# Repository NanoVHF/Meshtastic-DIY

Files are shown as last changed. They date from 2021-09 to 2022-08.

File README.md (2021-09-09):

# Meshtastic-DIY

Dear friends. If you have just learned what a Meshtastic-radio network is, if you are interested in the topic, if you already have a radio modem, and you would like to breathe life into it, then …
I have written a large series of 4 articles for the Russian-speaking community. This is more than the usual FAQ. This is a complete guide to action.
At the moment, the articles are written in Russian for a Russian-speaking audience. You can easily translate the article in your google chrome browser into your national language. Perhaps the Google translation will be slightly incorrect, with inaccuracies or errors.
Also, I am considering translating the article into real technical English.

PART 1 : https://habr.com/ru/post/568394/
The article is devoted to the general principles of the Meshtastic-network.

PART 2 : https://habr.com/ru/post/568526/
The article is devoted to branded radio modems with aliexpress stores.

PART 3 : https://habr.com/ru/post/568534/
The article is devoted to the radio amateur design and self-assembly of the radio modem (DIY).

PART 4 : https://habr.com/ru/post/569788/
A detailed step-by-step guide to flashing a radio modem and setting up a local radio network.

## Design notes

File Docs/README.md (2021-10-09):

# Documents

Documents, files and other text informations

* [Links](Links.md) - useful links
* [FAQ (ru)](FAQ_ru.md) - Frequently asced queries (in russian)
* LoRa modules V2 en.pdf - List of available LoRa modules
* LoRa modules V2.pdf - List of available LoRa modules (in russian) 
* Meshtastic DIY - Example of assembling a device on a 5x7 perforated board Translate.odt
* Meshtastic DIY - Пример сборки устройства на перфорированной плате 5x7 см.pdf
* Доклад на тему применения МШУ.pdf - paper about LNA using

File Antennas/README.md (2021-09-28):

# Meshtastic-DIY

Antenna drawings

[3El Yagee]("3El Yagee/") - Simple directional antenna

[Commercial](Commercial/) - Tested non-DIY antennas

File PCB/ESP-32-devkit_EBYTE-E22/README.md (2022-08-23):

# PCB

Based on [DIY v.1 shematics](https://github.com/NanoVHF/Meshtastic-DIY/tree/main/Schematics/E-Byte_E22) for using with `ESP32 WROOM-32 DevKit 38 pins` and `EBYTE E22-XXXM30S/E22-XXXM22S` modules.

Design by Denis Gorbunov (https://t.me/deaxx)

## Mesh-v1.01-2LCD-FreePins - Basic
- ESP32 WROOM-32 DevKit 38 pins,
- LORA: EBYTE E22-XXXM30S/E22-XXXM22S (selectable module). LoRa is connected via [an additional adapter board](#ebyte-e22-xxxmxxs-adapter-board),
- GPS,
- LCD (select different screens via jumpers: Vcc/GND or GND/Vcc),
- FR (free pins) - free ESP32 pins are placed along the edges of the board.

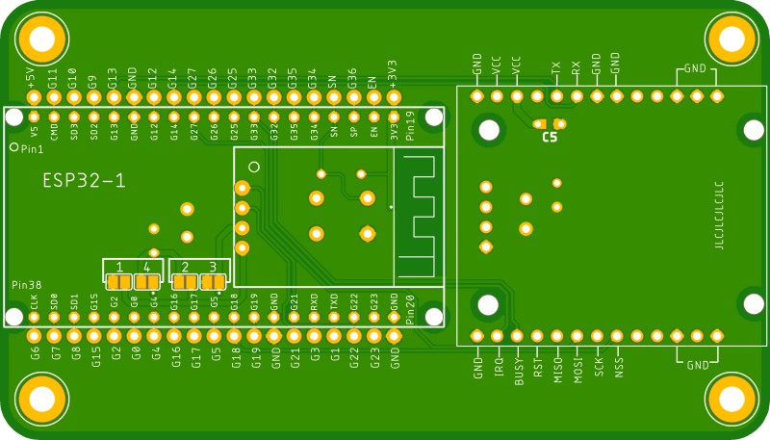
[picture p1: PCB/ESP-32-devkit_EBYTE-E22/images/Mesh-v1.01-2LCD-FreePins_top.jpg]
Mesh-v1.01-2LCD-FreePins_top

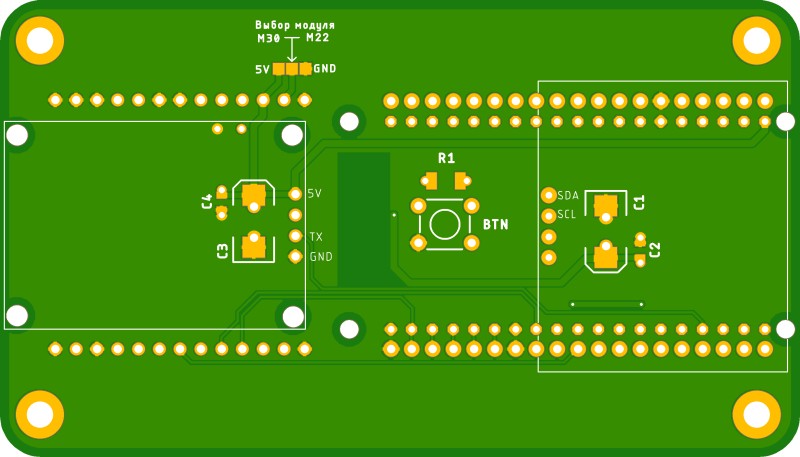
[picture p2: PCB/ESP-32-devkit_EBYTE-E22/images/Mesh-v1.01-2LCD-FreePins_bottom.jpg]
Mesh-v1.01-2LCD-FreePins_bottom


## Mesh-v1.02-2LCD - Narrow for placing inside a pipe
- ESP32 WROOM-32 DevKit 38 pins,
- LORA: EBYTE E22-XXXM30S/E22-XXXM22S (selectable module. LoRa module soldered directly to the board,
- GPS,
- LCD (select different screens via jumpers: Vcc/GND or GND/Vcc).

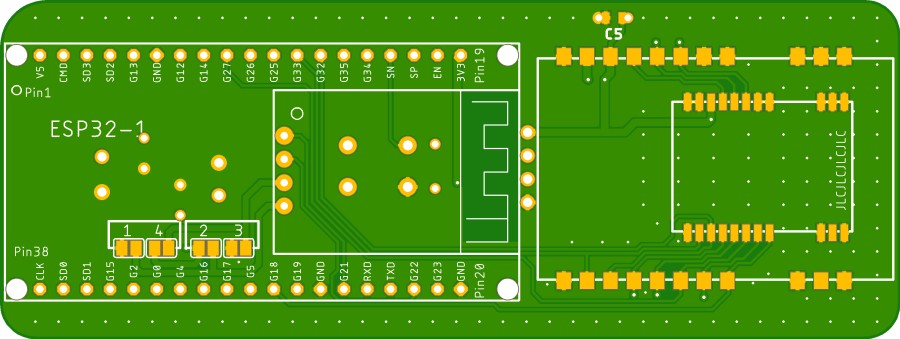
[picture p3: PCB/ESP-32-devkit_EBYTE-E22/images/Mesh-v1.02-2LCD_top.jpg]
Mesh-v1.02-2LCD_top

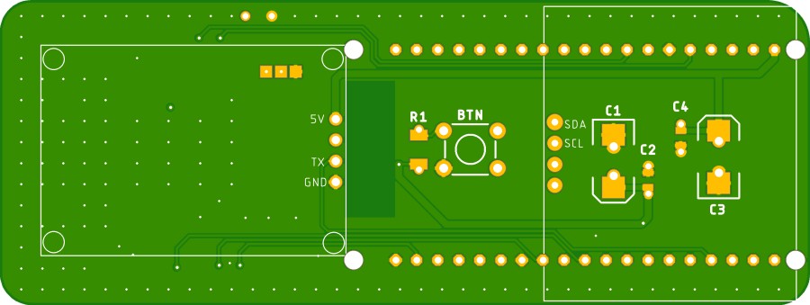
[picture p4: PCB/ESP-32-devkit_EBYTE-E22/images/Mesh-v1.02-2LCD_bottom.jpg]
Mesh-v1.02-2LCD_bottom


## Mesh-v1.02-2LCD-FreePins - Narrow for placing inside a pipe
- ESP32 WROOM-32 DevKit 38 pins,
- LORA: EBYTE E22-XXXM30S/E22-XXXM22S (selectable module. LoRa module soldered directly to the board,
- GPS,
- LCD (select different screens via jumpers: Vcc/GND or GND/Vcc),
- FR (free pins) - free ESP32 pins are placed along the edges of the board.

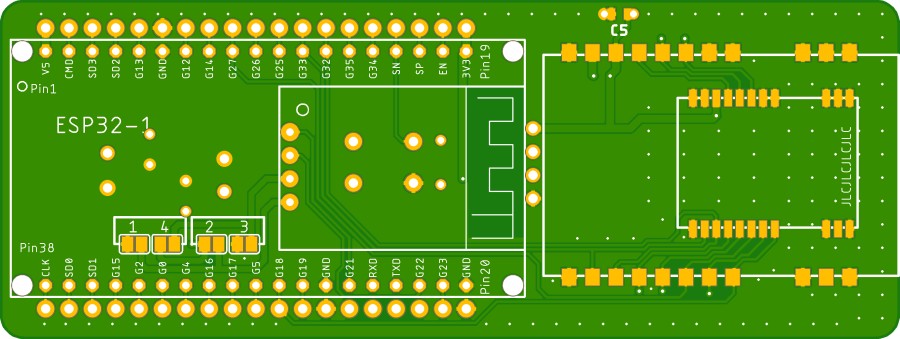
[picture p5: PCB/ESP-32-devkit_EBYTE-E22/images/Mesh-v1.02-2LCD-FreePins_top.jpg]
Mesh-v1.02-2LCD-FreePins_top

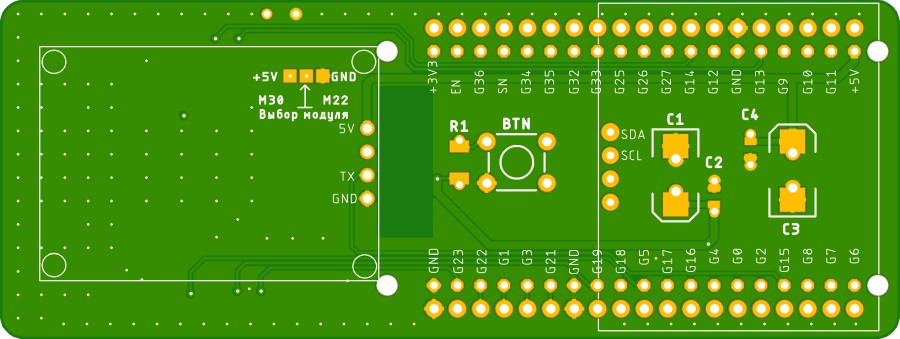
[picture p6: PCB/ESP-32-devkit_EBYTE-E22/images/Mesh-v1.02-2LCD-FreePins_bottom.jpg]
Mesh-v1.02-2LCD-FreePins_bottom


## Mesh-v1.03-2LCD-FreePins - Compact wearable
- ESP32 WROOM-32 DevKit 38 pins,
- LORA: EBYTE E22-XXXM30S/E22-XXXM22S (selectable module). LoRa is connected via [an additional adapter board](#ebyte-e22-xxxmxxs-adapter-board),
- GPS,
- LCD (select different screens via jumpers: Vcc/GND or GND/Vcc),
- FR (free pins) - free ESP32 pins are placed along the edges of the board.

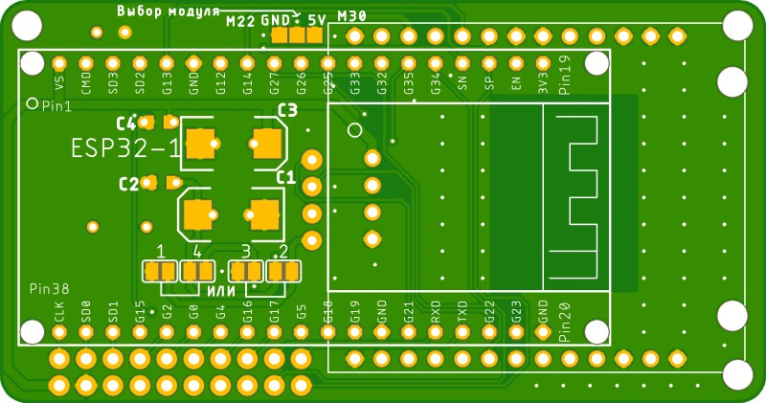
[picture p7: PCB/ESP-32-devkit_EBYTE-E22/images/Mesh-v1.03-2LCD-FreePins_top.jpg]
Mesh-v1.03-2LCD-FreePins_top

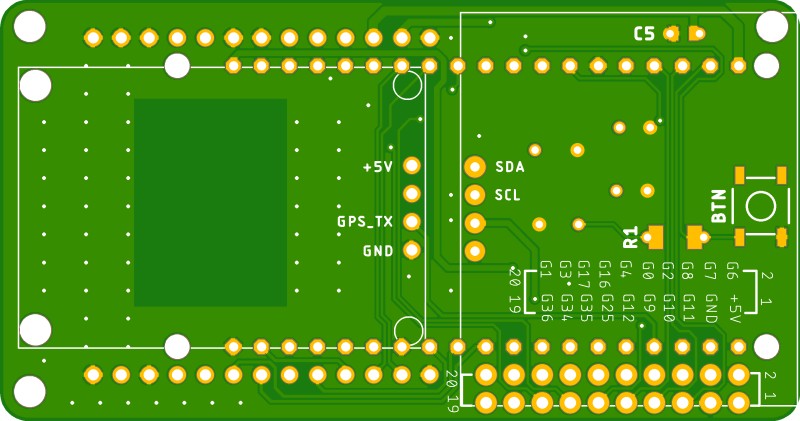
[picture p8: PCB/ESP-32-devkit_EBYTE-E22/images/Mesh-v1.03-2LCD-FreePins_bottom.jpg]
Mesh-v1.03-2LCD-FreePins_bottom


## Mesh-v1.04-TTGO-T8 - Compact wearable @ WROOWER T8 Lilygo
- ESP32 *WROOWER T8 Lilygo* 38 pins,
- LORA: EBYTE E22-XXXM30S/E22-XXXM22S (selectable module). LoRa is connected via [an additional adapter board](#ebyte-e22-xxxmxxs-adapter-board),
- GPS,
- LCD (select different screens via jumpers: Vcc/GND or GND/Vcc),
- FR (free pins) - free ESP32 pins are placed along the edges of the board.

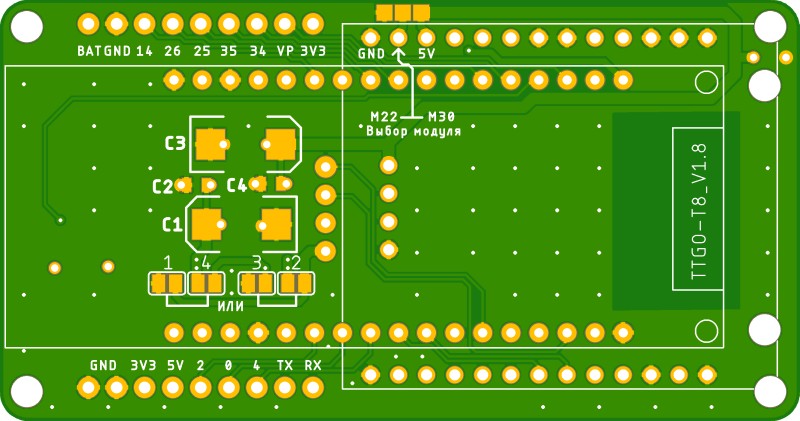
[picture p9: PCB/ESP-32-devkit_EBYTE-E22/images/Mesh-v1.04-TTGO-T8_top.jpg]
Mesh-v1.04-TTGO-T8_top

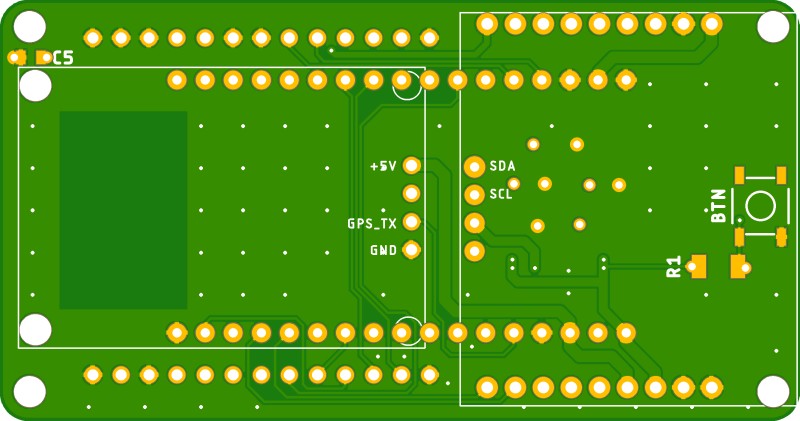
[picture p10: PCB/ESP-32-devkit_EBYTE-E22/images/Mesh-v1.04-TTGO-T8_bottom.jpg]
Mesh-v1.04-TTGO-T8_bottom


## Meshtastic-DIY_v1.05 - Square one
- ESP32 WROOM-32 DevKit 38 pins,
- LORA: EBYTE E22-XXXM30S/E22-XXXM22S (selectable module),
- GPS,
- LCD (select different screens via jumpers: Vcc/GND or GND/Vcc),
- Optional active buzzer.

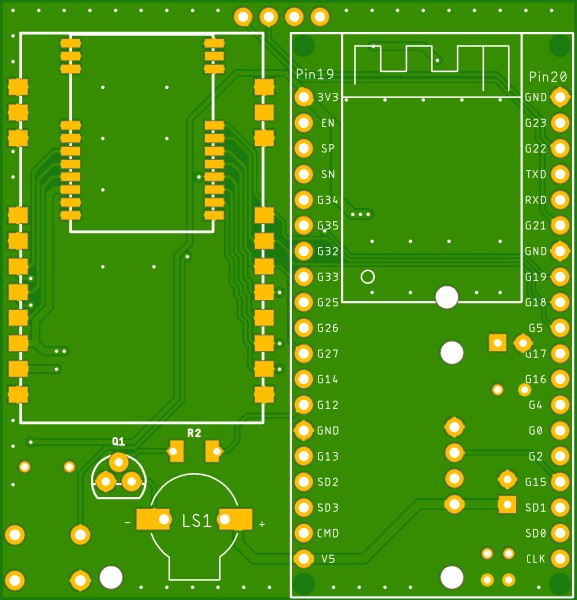
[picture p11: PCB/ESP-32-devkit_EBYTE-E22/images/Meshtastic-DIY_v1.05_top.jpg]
Meshtastic-DIY_v1.05_top

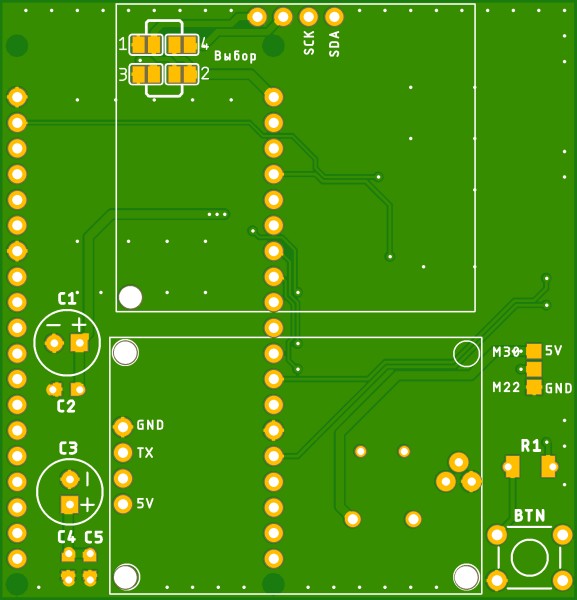
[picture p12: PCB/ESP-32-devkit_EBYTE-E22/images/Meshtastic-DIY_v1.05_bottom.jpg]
Meshtastic-DIY_v1.05_bottom


## Meshtastic-DIY_v1.06 - TTGO T-Energy T18 V3.0 HAT
- *Lilygo TTGO T-Energy T18 V3.0*,
- LORA: EBYTE E22-XXXM30S/E22-XXXM22S (selectable module),
- LCD (select different screens via jumpers: Vcc/GND or GND/Vcc).

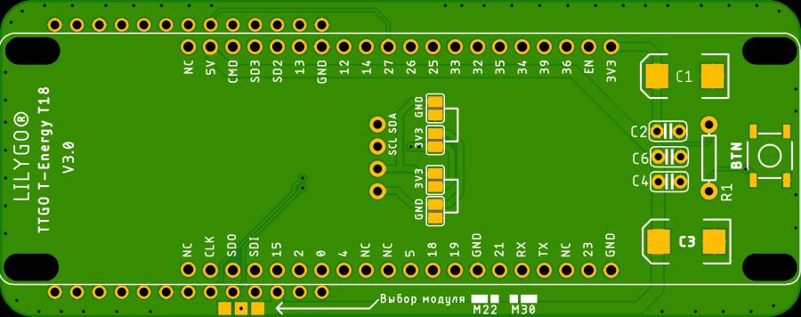
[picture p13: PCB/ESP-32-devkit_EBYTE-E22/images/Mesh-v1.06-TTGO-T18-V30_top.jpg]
Mesh-v1.06-TTGO-T18-V30_top

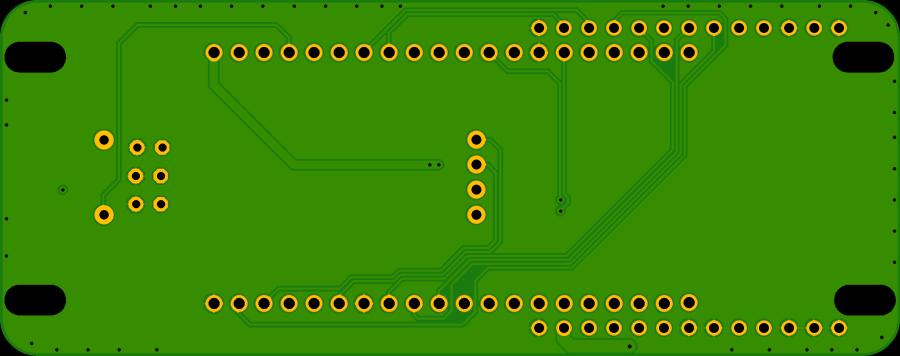
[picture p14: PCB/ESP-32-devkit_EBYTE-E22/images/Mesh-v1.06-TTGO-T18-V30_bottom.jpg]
Mesh-v1.06-TTGO-T18-V30_bottom


## EBYTE E22-xxxMxxS adapter board
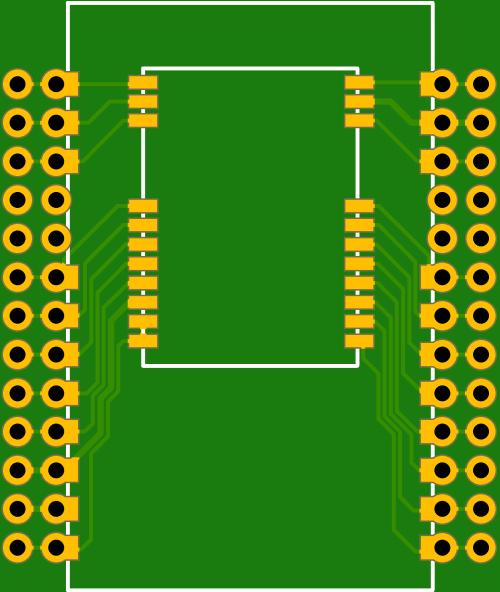
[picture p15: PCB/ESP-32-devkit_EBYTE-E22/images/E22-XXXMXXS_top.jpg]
E22-XXXMXXS_top

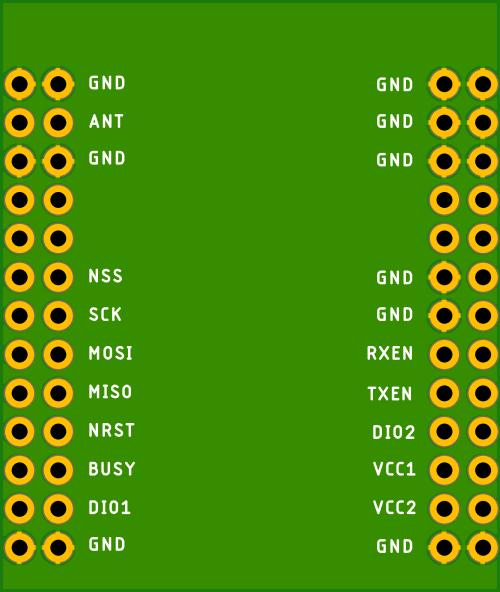
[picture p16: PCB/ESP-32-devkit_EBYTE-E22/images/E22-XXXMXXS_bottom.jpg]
E22-XXXMXXS_bottom


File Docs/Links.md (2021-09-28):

# Useful links

## Common links

* [Meshtastic.org](https://meshtastic.org/) - main site of project
* [Meshtastic.ru](https://meshtastic.ru/) - site of russian meshtastic team
* [Meshtastic map](https://canvis.app/meshtastic-map) - map of meshtastic nodes
* [Meshtastic forum](https://meshtastic.discourse.group) - meshtastic forum at discourse.group

## Hardware

* [Aliexpress aluminium case](https://aliexpress.ru/item/32226417158.html) - aluminium case for PCB 45x45x18.5 mm external
* [Aliexpress IPEX-SMA pigtail](https://aliexpress.ru/item/4001038251087.html) - IPEX/IPX/U.fl jack to SMA socket pigtail with seal
* [Aliexpress IPEX-SMA pigtail](https://aliexpress.ru/item/4000979336586.html) - IPEX/IPX/U.fl jack to SMA jack pigtail
* [Aliexpress IPEX to SMA converter](https://a.aliexpress.com/_AlJSeS) - unchecked
* [Aliexpress IPEX to SMA converter 2](https://a.aliexpress.com/_AE24qa) - unchecked
* [Aliexpress base antenna 868 MHz](https://a.aliexpress.com/_AtphUu) - base station antenna with N type jack
* [Aliexpress antenna 868 MHz](https://aliexpress.ru/item/32972870968.html) - in-hole antenna with U.fl type jack
* [Antenna on magnetic base 868 MHz](https://www.triada-ant.ru/catalogue/antenny/2/11/133/) - unchecked

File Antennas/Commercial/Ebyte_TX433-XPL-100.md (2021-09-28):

# Ebyte TX433-XPL-100 

Ebyte TX433-XPL-100 Antenna 433MHz High Gain SMA jack Magnetic Base Omnidirectional 1m feeder 

Purchase link (to 2m feeder version) https://a.aliexpress.com/_AdqBiV

Inexpencive lambda/4 whip antenna.

Test setup: NanoVNA V2 china clone, NanoVNA_QT_GUI profram, canned peaches can. Sweep from 390 to 470 MHz, 200 poins.

[Impedances](TX433-XPL-100.csv)

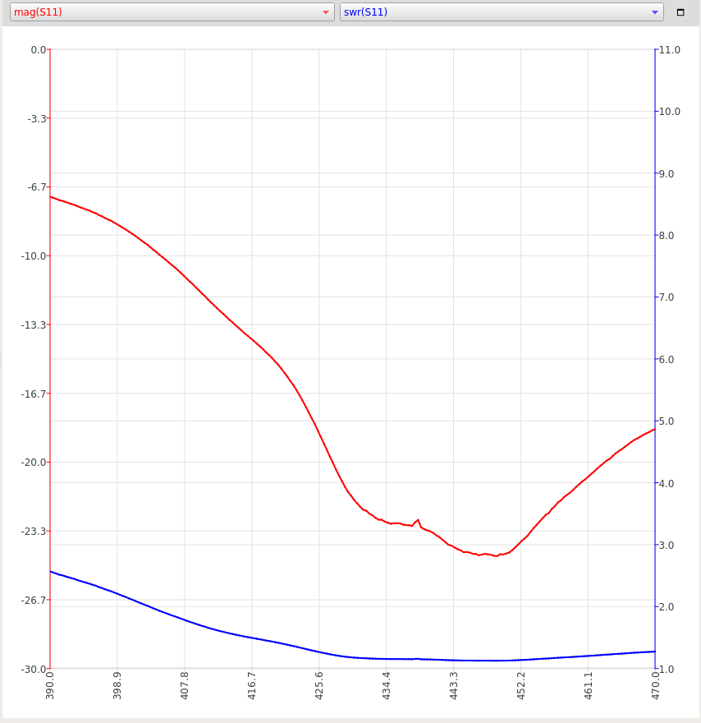
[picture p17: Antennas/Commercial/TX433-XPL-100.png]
SWR graph


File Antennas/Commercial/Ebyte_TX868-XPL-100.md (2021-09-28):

# Ebyte TX868-XPL-100 

Ebyte TX868-XPL-100 Antenna 868MHz 3.5dBi High Gain Omnidirectional SMA Interface Magnetic Base 1m Feeder 

Purchase link: https://a.aliexpress.com/_987405

Inexpencive collinear antenna.

Test setup: NanoVNA V2 china clone, NanoVNA_QT_GUI profram, canned peaches can. Sweep from 790 to 950 MHz, 200 poins.

[S11 parameters](TX868-XPL-100.s1p), [impedances](TX868-XPL-100.csv)

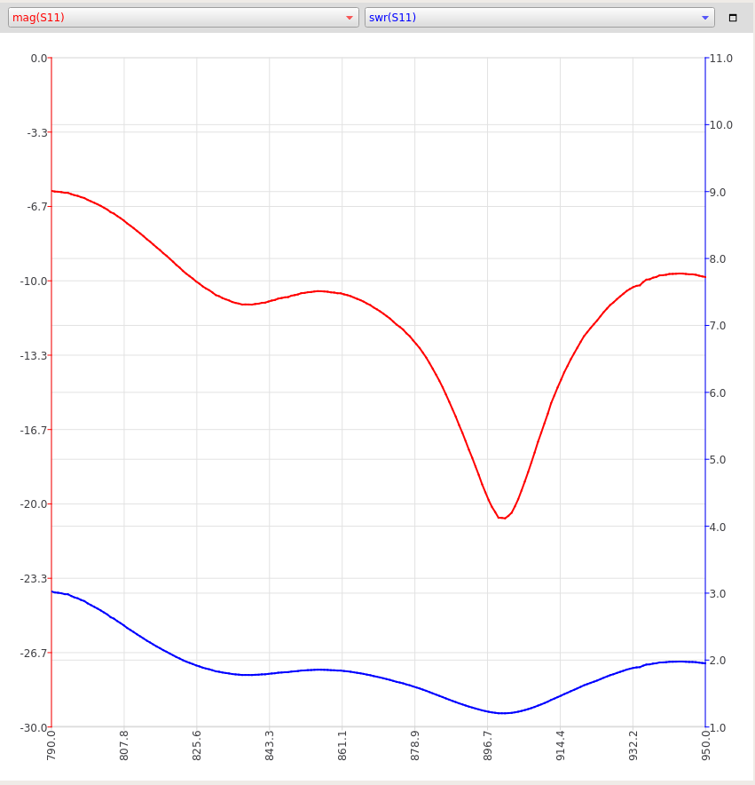
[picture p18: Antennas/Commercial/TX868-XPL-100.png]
SWR graph


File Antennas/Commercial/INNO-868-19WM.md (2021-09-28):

# INNO-868-19WM

White 868MHz LORA Antenna SMA Male Connector 868 MHz 21cm RP-SMA/u.FL Pigtail Cable

Purchase link: https://a.aliexpress.com/_AY2JaH

Test setup: NanoVNA V2 china clone, NanoVNA_QT_GUI profram, canned peaches can. Sweep from 790 to 950 MHz, 200 poins.

[S11 parameters 1](INNO-868-19WM.s1p), [2](INNO-868-19WM-2.s1p), [mpedance](INNO-868-19WM.csv)

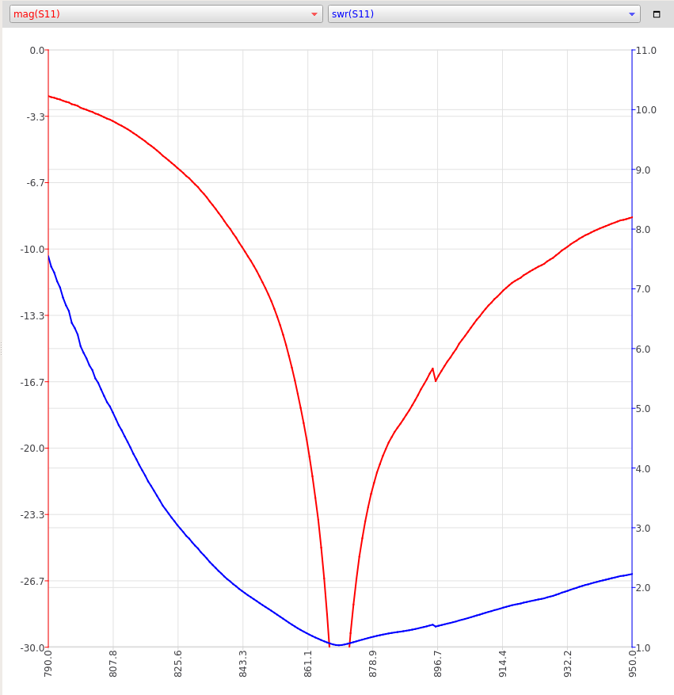
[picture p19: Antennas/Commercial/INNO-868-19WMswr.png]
SWR graph


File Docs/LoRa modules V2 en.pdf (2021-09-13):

### E-byte modules

Module | Chip | Freq (MHz) | PWR (dBm) | Uvdd (V) | Peculiarities | Price $
E22-900M22S | SX1262 | 868 | 22 | 3.3 | Simple module. No LNA. No PA. Has TCXO. | 9
E22-900M30S | SX1262 | 868 | 30 | 5 | Powerful module. Has LNA. Has PA. Has TCXO. | 11
E22-400M22S | SX1268 | 433 | 22 | 3.3 | Simple module. No LNA. No PA. Has TCXO. | 6
E22-400M30S | SX1268 | 433 | 30 | 5 | Powerful module. Has LNA. Has PA. Has TCXO. | 10
E19-868M30S | SX1276 | 868 | 30 | 5 | Powerful module. Has LNA. Has PA. No TCXO. | 10…12
E19-868M20S | SX1276 | 868 | 20 | 3.3 | Simple module. No LNA. No PA. No TCXO. | 5…6
E19-900M20S2 | SX1276 | 868 | 20 | 3.3 | Simple module. No LNA. No PA. No TCXO. | 4…5
E19-433M30S | SX1278 | 433 | 30 | 5 | Powerful module. Has LNA. Has PA. No TCXO. | 6…7
E19-433M20SC | SX1278 | 433 | 20 | 3.3 | Simple module. No LNA. No PA. No TCXO. | 4…5
E19-433M20S2 | SX1278 | 433 | 20 | 3.3 | Simple module. No LNA. No PA. No TCXO. | 4…5
E220-900M22S | LLCC68 | 868 | 22 | 3.3 | Simple module. No LNA. No PA. ? TCXO. | 3…5
E220-900M30S | LLCC68 | 868 | 30 | 5 | Powerful module.. Has LNA. Has PA. ? TCXO. | ?
E220-400M22S | LLCC68 | 433 | 22 | 3.3 | Simple module No LNA. No PA. ? TCXO. | 3…4
E220-400M30S | LLCC68 | 433 | 30 | 5 | Powerful module Has LNA. Has PA. ? TCXO. | ?

Prices are indicative for EBYTE IOT Factory Store or CDSENET IOT Module Store

### G-NiceRF modules

Module | Chip | Freq (MHz) | PWR (dBm) | Uvdd (V) | Peculiarities | Price $
LoRa1262F30 | SX1262 | 868 | 30 | 5…6 | Powerful module. No LNA. Has PA. Has TCXO. | 12…14
LoRa1262F30 | SX1262 | 315 | 30 | 5…6 | Powerful module. No LNA. Has PA. Has TCXO. | 12…14
LoRa1268F30 | SX1268 | 433 | 30 | 5…6 | Powerful module. No LNA. Has PA. Has TCXO. | 14
LoRa1262-868 | SX1262 | 868 | 22 | 3.3 | Simple module. No LNA. No PA. Has TCXO. | 9
LoRa1268-433 | SX1268 | 433 | 22 | 3.3 | Simple module. No LNA. No PA. Has TCXO. | 10…14
LoRa1276-C1-868 | SX1276 | 868 | 20 | 3.3 | Simple module. No LNA. No PA. No TCXO. | 5…7
LoRa1278-C1-433 | SX1278 | 433 | 20 | 3.3 | Simple module. No LNA. No PA. NO TCXO. | 5…7
LoRa-CC68-868 | LLCC68 | 868 | 22 | 3.3 | Simple module. No LNA. No PA. ? TCXO. | 4
LoRa-CC68-433 | LLCC68 | 433 | 22 | 3.3 | Simple module. No LNA. No PA. ? TCXO. | 4
LoRa1276F30 | SX1276 | 868 | 27 | 5…6 | Powerful module. No LNA. Has PA. No TCXO. | 13
LoRa1278F30 | SX1278 | 433 | 30 | 5…6 | Powerful module. No LNA. Has PA. No TCXO. | 13
LoRa1276-868 | SX1276 | 868 | 20 | 3.3 | Simple module. No LNA. No PA. No TCXO. | 7
LoRa1278-433 | SX1278 | 433 | 20 | 3.3 | Simple module. No LNA. No PA. No TCXO. | 7

Prices are indicative for G-NiceRF Official Store or NiceRF Wireless Technology CO., LTD. Modules are usually sold in 2 or 4 pieces.

Green color:- modules are officially supported by firmware and / or tested.

Yellow color: -modules are not officially supported by firmware, but have already been tested.

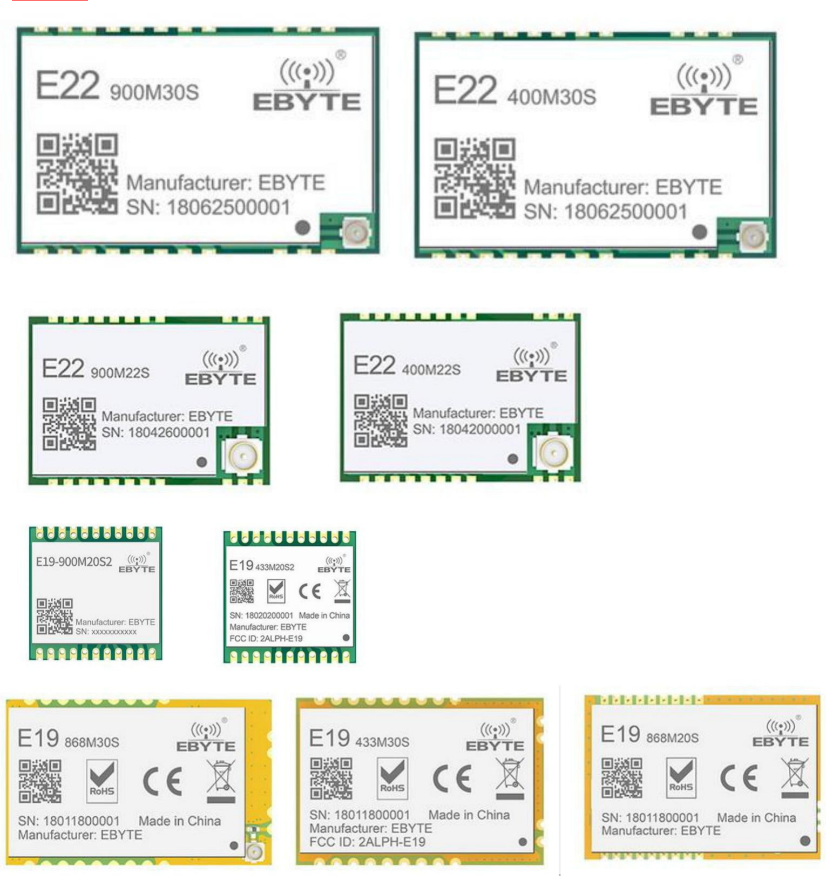
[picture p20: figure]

Color red: -modules are not officially supported by firmware, not tested but work is in progress.

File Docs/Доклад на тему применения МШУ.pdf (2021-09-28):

Расширенный доклад на тему применения МШУ.

Когда вы увидели некое китайское поделие на досках Али или Ебай под видом МШУ за относительно небольшие деньги, то не нужно бросаться и сразу заказывать его. Это же В ОСОБЕННОСТИ относится к телевизионным усилителям.

Объясняю почему. Сегодняшний уровень прогресса уже давно дошел да того, что одночиповые трансиверы типа SI4432, SX1276/SX1262, BK4815
трансиверов | Zastone | или | QYTа | или | подобные | изделия | (включая
супергетеродины типа Wouxun и Аргут) обеспечивают чуйку в пределах 0,2мкВ или, даже, лучше. Ставить МШУ на подобные аппараты смысла нет никакого!
- Во-первых: улучшений вы скорее всего не увидите;
- Во-вторых: испортите и без того не сильно высокие динамические характеристики «однояицовых» аппаратов. Исключение – сильно специфичные условия, типа 50м до крыши, но там отдельная тема разговора, смысл которой – сделать правильную коммутацию и питание.

Начните с того, что делайте лучше нормальные антенны - и будет вам аж счастье-СЧАСТЬЕ! Не Харченки всякие линейные и не рулеточные диполи, а хотя бы 6...8 эл Яги, а ещё лучше - монобендовые крестики. Да, это довольно трудоёмко, зато – есть эффект. И совсем круто будет - когда вы начнёте крутить мышам хвосты в спирали. Начинать нужно смело от 3х витков. Антенна получается достаточно простой и не сильно габаритной. Тогда ГШ сильно опечалится и сбежит нах, ибо никто не будет на неё реагировать.

Теперь по поводу конкретно МШУ, продаваемых на АЛИ

Во-первых, никакой гарантии, что вам их продадут нормальные и фирменные нет. У меня большой опыт закупок подобной СВЧ лабуды, не только для дома, а и для производства. Даже на фирмах бывает залипуху подсовывают; во-вторых, когда китайцы пишут полосу 0Гц - 100тыс. гигаерц и усиление 20...1000дБ – это 250% обман! Почему так? В даташитах на некоторые МС, действительно, пишут полосу работы от 50МГц до 6ГГц усиление 12...20дБ. Но, это в строго конкретном участке частот, куда микросхема идеально отстроена, а это значит, что натуральные 12...20дБ усиления будут примерно в полосе 50...100МГц. Т.е. эти МС надо обязательно согласовывать туда, куда их планируется использовать. Во всей остальной полосе будет повышенный уровень шума, гораздо ниже усиление и вообще, несогласованная работа микросхем МШУ чревата "художественным свистом" с последующим выгоранием.

Основные ТТХ МШУ

Основной характеристикой МШУ является уровень собственных шумов. Относительно ЧЕГО? По отношению к вносимым шумам последующего за МШУ каскада, в реальности – к космическим шумам эфира и шумовой обстановки вокруг антенны. Применять МШУ есть смысл, когда антенна сама по себе имеет малый коэф. усиления и/или когда надо компенсировать потери в длинном кабеле.

- Главный параметр МШУ - "Коэффициент шума (Кш)"

Хорошая цифра Кш - это 0,5...1. Меньше 0.2 Кш получить технически очень сложно и страшно дорого. Когда китайцы пишут про 0.1дБ на спутниковой головке – это, тоже чистый обман! Из доступных МШУ в России на сегодняшний день – это МС серий SPF, BGA и некоторые MGA с Кш=0,5...1,5дб. Всё что имеет Кш лучше чем 0.5 – достать обычному
смертному | практически | невозможно, | (топовые | изделия | оборонного
назначения находятся под санкциями и в Россию поставки официально запрещены) чего бы там китайцы не писали про свои поделки! Обычно Кш<1 в китайских поделиях тоже нет. (Исключения есть, но это надо очень сильно заморочиться с поисками). Залипуху с неизвестной перемаркировкой и подделками под оригинальные SPF вообще не рассматриваем. Что там китайцы запаяли – неизвестно.

МШУ с Кш>3 – это явно плохие устройства, т.к. улучшение сигнала всего на 1-3дБ с практической точки зрения не имеют смысла. Такой МШУ назвать малошумящим язык даже не поворачивается назвать.

Для реализации всех преимуществ малошумящих микросхем требуется очень хорошая экранировка самого тракта МШУ, очень чистое питание и главное -подходящий не фонящий QTH. В городе реализовать параметры такого МШУ практически, в 99% случаев невозможно, т.к. сам радиоэфир имеет большой уровень помех.

Коэффициент шума большинства раций составляет 5-10дБ. Если мы применяем МШУ с коэф. шума =1, то улучшаем приём на разницу между этими коэффициентами. Т.е. в данном случае на те же 5-10дБ. По шкале Sметра – это 1-3 балла. В реальном же эфире – это возможность услышать сигнал, который в обычном состоянии находится примерно под шумами рации, в том случае, если антенна позволяет принять сигнал на более качественном приёмнике.

Как говорилось выше – большинство современных приёмников имеют вполне неплохой приёмный тракт, а сигналы со спутников относительно сильные. (Относительно — это значит, что транспондеры видно и слышно на обычный диполь, и специально применения МШУ не требуется)

- Параметр "Коэффициент усиления"

Ку имеет смысл, но он в большинстве случаев вторичен.

Высокий | уровень | усиления | на | практике | позволяет
"прошить"/скомпенсировать потери на длинном кабеле. В особенности, это касается частот выше 500…700МГц, где потери на длине кабеля от 10м и длиннее, довольно существенны.

Скажем, если у вас антенна на крыше дома, а вы на 1-5 этажах от 9-этажки, то МШУ с малым уровнем шума и высоким Ку позволит существенно улучшить качество приёма имеющейся станции.

Высокий уровень усиления МШУ на балконной антенне кроме как увеличения уровня принимаемого шума в большинстве случаев мало что даст. Тут, как раз, существенно сказывается уровень шумов в вашем QTH: шумы от всяких импульсных БК, компьютеров и проводов.

- Параметры ОТЛИЧНОГО МШУ: Кш=0.3...0.5дБ; Ку=20...25дБ (спец. транзисторы; SPF5122 и др.)
- Параметры ХОРОШЕГО МШУ: Кш=0.5...1дБ; Ку=15...20дБ (ATF54143; SPF5043 и др.)
- Параметры ПРИЕМЛЕМОГО МШУ: Кш1.2...1.8дБ; Ку=12...15дБ (транзисторы типа BF998 и похожие)

ВСЁ ЧТО ХУЖЕ ЭТИХ ПАРАМЕТРОВ НЕ ИМЕЕТ СМЫСЛА ПОКУПАТЬ ОТ СЛОВА СОВСЕМ!!!

Абсолютное большинство ТВ усилителей относятся к классу "плохих", т.е. сильно шумящих усилителей!... за, очень редким исключением.

Всем спасибо за внимание, доклад окончил.

Александр: @ Nano_VHF

Релиз: декабрь 2017г.

UPD: 28.09.2021

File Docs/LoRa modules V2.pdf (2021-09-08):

### E-byte modules

Module | Chip | Freq (MHz) | PWR (dBm) | Uvdd (V) | Peculiarities | Price $
E22-900M22S | SX1262 | 868 | 22 | 3.3 | Простой модуль. Нет LNA. Нет PA. Есть TCXO. | 9
E22-900M30S | SX1262 | 868 | 30 | 5 | Мощный модуль. Есть LNA. Есть PA. Есть TCXO. | 11
E22-400M22S | SX1268 | 433 | 22 | 3.3 | Простой модуль. Нет LNA. Нет PA. Есть TCXO. | 6
E22-400M30S | SX1268 | 433 | 30 | 5 | Мощный модуль. Есть LNA. Есть PA. Есть TCXO. | 10
E19-868M30S | SX1276 | 868 | 30 | 5 | Мощный модуль. Есть LNA. Есть PA. Нет TCXO. | 10…12
E19-868M20S | SX1276 | 868 | 20 | 3.3 | Простой модуль. Нет LNA. Нет PA. Нет TCXO. | 5…6
E19-900M20S2 | SX1276 | 868 | 20 | 3.3 | Простой модуль. Нет LNA. Нет PA. Нет TCXO. | 4…5
E19-433M30S | SX1278 | 433 | 30 | 5 | Мощный модуль. Есть LNA. Есть PA. Нет TCXO. | 6…7
E19-433M20SC | SX1278 | 433 | 20 | 3.3 | Простой модуль. Нет LNA. Нет PA. Нет TCXO. | 4…5
E19-433M20S2 | SX1278 | 433 | 20 | 3.3 | Простой модуль. Нет LNA. Нет PA. Нет TCXO. | 4…5
E220-900M22S | LLCC68 | 868 | 22 | 3.3 | Простой модуль. Нет LNA. Нет PA. ? TCXO. | 3…5
E220-900M30S | LLCC68 | 868 | 30 | 5 | Мощный модуль. Есть LNA. Есть PA. ? TCXO. | ?
E220-400M22S | LLCC68 | 433 | 22 | 3.3 | Простой модуль. Нет LNA. Нет PA. ? TCXO. | 3…4
E220-400M30S | LLCC68 | 433 | 30 | 5 | Мощный модуль. Есть LNA. Есть PA. ? TCXO. | ?

Цены указаны ориентировочно для магазинов EBYTE IOT Factory Store или CDSENET IOT Module Store

### G-NiceRF modules

Module | Chip | Freq (MHz) | PWR (dBm) | Uvdd (V) | Peculiarities | Price $
LoRa1262F30 | SX1262 | 868 | 30 | 5…6 | Мощный модуль. Нет LNA. Есть PA. Есть TCXO. | 12…14
LoRa1262F30 | SX1262 | 315 | 30 | 5…6 | Мощный модуль. Нет LNA. Есть PA. Есть TCXO. | 12…14
LoRa1268F30 | SX1268 | 433 | 30 | 5…6 | Мощный модуль. Нет LNA. Есть PA. Есть TCXO. | 14
LoRa1262-868 | SX1262 | 868 | 22 | 3.3 | Простой модуль. Нет LNA. Нет PA. Есть TCXO. | 9
LoRa1268-433 | SX1268 | 433 | 22 | 3.3 | Простой модуль. Нет LNA. Нет PA. Есть TCXO. | 10…14
LoRa1276-C1-868 | SX1276 | 868 | 20 | 3.3 | Простой модуль. Нет LNA. Нет PA. Нет TCXO. | 5…7
LoRa1278-C1-433 | SX1278 | 433 | 20 | 3.3 | Простой модуль. Нет LNA. Нет PA. Нет TCXO. | 5…7
LoRa-CC68-868 | LLCC68 | 868 | 22 | 3.3 | Простой модуль. Нет LNA. Нет PA. ? TCXO. | 4
LoRa-CC68-433 | LLCC68 | 433 | 22 | 3.3 | Простой модуль. Нет LNA. Нет PA. ? TCXO. | 4
LoRa1276F30 | SX1276 | 868 | 27 | 5…6 | Мощный модуль. Нет LNA. Есть PA. Нет TCXO. | 13
LoRa1278F30 | SX1278 | 433 | 30 | 5…6 | Мощный модуль. Нет LNA. Есть PA. Нет TCXO. | 13
LoRa1276-868 | SX1276 | 868 | 20 | 3.3 | Простой модуль. Нет LNA. Нет PA. Нет TCXO. | 7
LoRa1278-433 | SX1278 | 433 | 20 | 3.3 | Простой модуль. Нет LNA. Нет PA. Нет TCXO. | 7

Цены указаны ориентировочно для магазинов G-NiceRF Official Store или NiceRF Wireless Technology CO.,LTD.

Модули обычно продаются по 2шт или 4шт.

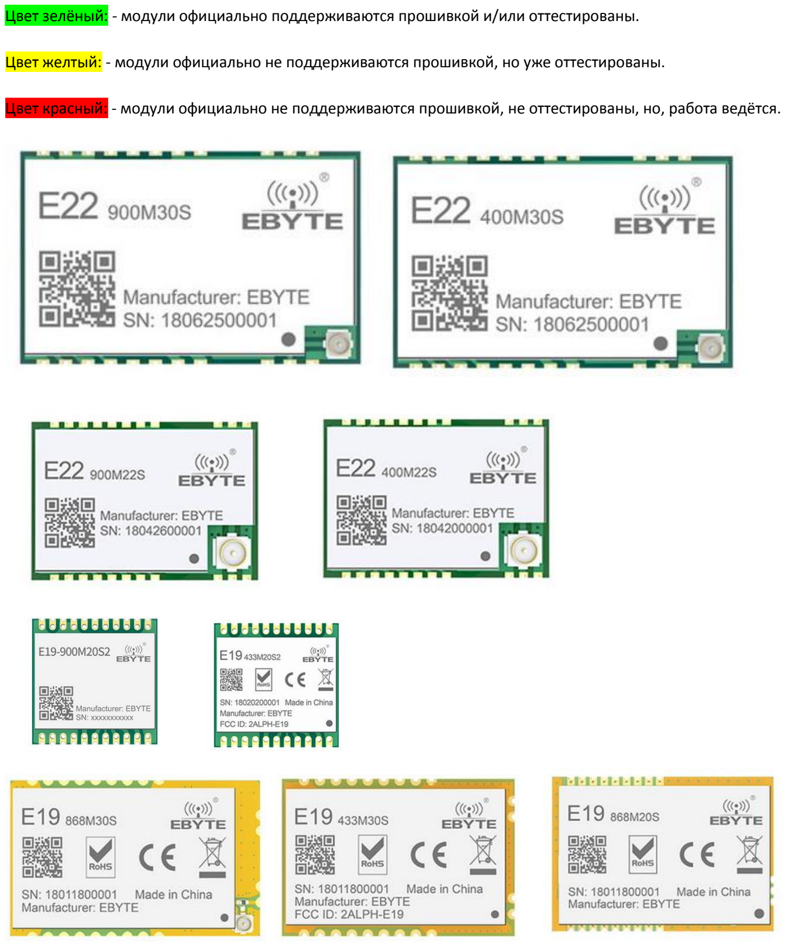
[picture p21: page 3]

Цвет зелёный: - модули официально поддерживаются прошивкой и/или оттестированы.

Цвет желтый: - модули официально не поддерживаются прошивкой, но уже оттестированы.

Цвет красный: - модули официально не поддерживаются прошивкой, не оттестированы, но, работа ведётся.

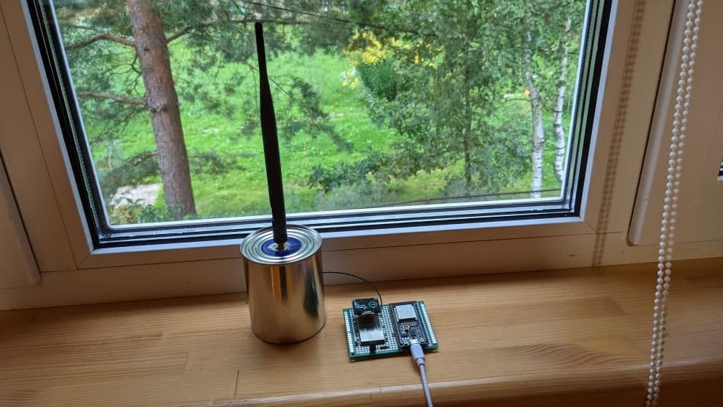
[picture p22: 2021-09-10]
Photos/Design_1.jpg

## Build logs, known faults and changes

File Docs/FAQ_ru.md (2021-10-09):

# ЧаВо (FAQ на русском)

Часто задаваемые вопросы и ответы, собранные с разных сайтов, форумов и чатов

## Общие вопросы

### Что такое Meshtastic ?

Meshtastic - самоорганизующаяся радиосеть передачи текстовых сообщений на основе технологии LoRa. 

### А подробнее?

Сеть Meshtastic состоит из смартфонов (пока только под андроидом) и вспомогательных устройств, которые связаны со смартфоном по интерфейсу Bluetooth, а между собой - по радио с использованием технологии LoRa. На смартфоны ставится клиент, с точки зрения пользователя - мессенджер, который обменивается сообщениями с вышеупомянутым устройством. Дальше они передают сообщения по радиоканалу на так называемых безлицензионных частотах (в России диапазоны 433 и 868 МГц). Каждое устройство может быть ещё и ретранслятором, автоматически обнаруживать новые устройства в эфире и строить таблицу маршрутизации сообщений.

Просто почитать сообщения можно и без смартфона, если устройство оборудовано экраном и кнопками навигации. На самых дешевых вариантах их (сюрприз, сюрприз) нет.

В любом варианте система Meshtastic позволяет без какой-либо дополнительной инфраструктуры, то есть там и тогда, где не работает сотовая связь, интернет и другие блага цивилизации, поддерживать связь друг с другом.

### Законно ли это ?

Использование LoRa устройств законно и не требует лицензии при условии соблюдения региональных ограничений на мощность и диапазон частот передатчика. В Российской Федерации это 25 мВт и диапазоны EU433 и RU864-870, описанные в документе [RP2-1.0.2 LoRaWAN® Regional Parameters](https://lora-alliance.org/resource_hub/rp2-102-lorawan-regional-parameters/) Исключение - территории аэродромов и аэропортов.

На русском языке это кратко описано [в статье на сайте русского альянса производителей интернета вещей](https://iotas.ru/media/news_aiv/161/).

Основание - [решение ГКРЧ при Мининформсвязи России №07-20-03-001 от 07.05.2007 "О выделении полос радиочастот устройствам малого радиуса действия" (действует до мая 2027 года)](https://digital.gov.ru/ru/documents/4039/), приложение №11. [Статья с кратким изложением](https://itechinfo.ru/content/%D1%81%D1%82%D1%80%D0%BE%D0%B8%D1%82%D0%B5%D0%BB%D1%8C%D1%81%D1%82%D0%B2%D0%BE-%D1%81%D0%B5%D1%82%D0%B5%D0%B9-lora-%D0%B2-%D1%80%D1%84)

### Где почитать подробнее?

Документация на русском языке пока в процессе перевода. Если же вы читаете технический английский, вам дорога на сайт [Meshtastic.org](https://meshtastic.org/)

### Здесь могут быть ваши вопросы 

## Вопросы начинающих

### С чего начать?

Минимальный план действий:

* Приобрести оборудование
* Прошить в него нужную фирмварь
* Подключить к нему смартфон
* Наслаждаться общением

Прошивка оборудования описана на том же сайте в разделах [Flashing ESP32](https://meshtastic.org/docs/getting-started/flashing-esp32) и [Flashing nRF52](https://meshtastic.org/docs/getting-started/flashing-nrf52) для устройств на микроконтроллерах ESP32 и nRF52 соответственно

Подключение смартфона (пока только с андроидом) описано [в соответствующем разделе сайта мештастика](https://meshtastic.org/docs/software/android/android-installation)

### Здесь могут быть ваши вопросы 

## Технические вопросы

### Можно ли построить на одном радиомодеме двухдиапазонное устройство?

Нет. Хотя некоторые микросхемы, например, семейства SX126x по спецификации поддерживают широкий диапазон частот, антенны и входящие в радиомодули усилители и схемы согласования узкополосны и работают лишь в том диапазоне частот, на который рассчитан модуль.

### Здесь могут быть ваши вопросы

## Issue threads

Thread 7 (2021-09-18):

Custom PCB

puzzled-pancake, 2021-09-18:
I designed a custom PCB based on the schematic.
I am not a professional in designing or making PCBs please tell me if I made a mistake or if you want to add anything else to the PCB.

Cost for 5 PCBs from China is $6.20 usd + Shipping

This is based on 38 Pin ESP32 board.

https://github.com/puzzled-pancake/Meshtastic-DIY/tree/main/Schematics/Meshtastic%20PCB%20untested

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

puzzled-pancake, 2021-09-18:
**Russian translated using google translate**
Я разработал собственную печатную плату на основе схемы.
Я не профессионал в проектировании или изготовлении печатных плат, пожалуйста, скажите мне, если я допустил ошибку, или если вы хотите добавить что-нибудь еще к печатной плате.

Стоимость 5 печатных плат из Китая - 6.20 долларов США + доставка

Это основано на 38-контактной плате ESP32.

https://github.com/puzzled-pancake/Meshtastic-DIY/tree/main/Schematics/PCB%20Example%20test

osmanovv, 2021-09-18:
Could you please also sketch it for the 30-pins version of ESP32-WROOM-32 DevKit?

osmanovv, 2021-09-18:
And perhaps variants with a horizontal layout

puzzled-pancake, 2021-09-19:
> Could you please also sketch it for the 30-pins version of ESP32-WROOM-32 DevKit?

Done a 30 pin vertical I will work on a horizontal layout for the 30pin and 38pin

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

puzzled-pancake, 2021-09-19:
Is this horizontal layout okay?

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

zonder16, 2021-11-15:
Could you please also sketch it for the version of LILYGO®TTGO T8 V1.8 ESP32 - WROVER 8MB PSRAM TF? [Liligo ttgo t8](https://a.aliexpress.com/_9wNify)

NanoVHF, 2022-07-08:
Tested versions of boards: https://github.com/NanoVHF/Meshtastic-DIY/tree/main/PCB/ESP-32-devkit_EBYTE-E22

Closed 2022-07-08.

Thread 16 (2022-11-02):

E22-400T33S support

karfam, 2022-11-02:
Congratulations on the project

Does the it support the new E22-400T**33**S due to increased consumption?

https://www.ebyte.com/en/product-view-news.html?id=454

osmanovv, 2022-11-02:
Hi @karfam, as I could see from the name of a new module - it's an UART, not SPI (letter "T" in the name). At this point Meshtastic firmware supports only SPI radio modules with letter "M" in the name, like "E22-400M30S",  "E22-400M22S",  "E22-900M30S", "E22-900M22S".

karfam, 2022-11-02:
Yes missed that. Just emailed ebyte to see if they plan a 2 watt SPI module.

@Update
They just replied and there is E22-400**M**33S

karfam, 2022-11-03:
According to manufacturer the Consumption of the module is :
**TX current（mA） 850 1000 1200 Instant power consumption 33dbm**

TTGO T-Energy uses SY8089 step down regulator.

[TTGO T-Energy Schematic](https://github.com/LilyGO/LILYGO-T-Energy/blob/master/t18_v3.0.pdf)

 The SY8089 and SY8089A are high-efficiency, high
frequency synchronous step-down DC-DC regulator IC
capable of delivering up to 2A output current.

[SY8089 Datasheet](https://datasheet.lcsc.com/szlcsc/Silergy-Corp-SY8089AAAC_C78988.pdf)

Probably the 18650 battery will be fine with the 1.2Amp discharge for a few ms

SlitheringMule, 2023-06-09:
You need 5V for max power output

kpbicka, 2024-02-14:
У меня модуль E22-400M33S SX1268 433/470MHz 2W SPI Chip LoRa Module

в консоль пишет такое:
WARN  | 1 SX126xInterface(cs=18, irq=33, rst=23, busy=32)
DEBUG | 1 SX126X_DIO3_TCXO_VOLTAGE defined, using DIO3 as TCXO reference voltage at 1.800000 V
INFO  | 1 Starting meshradio init...
DEBUG | 1 (bw=125, sf=11, cr=4/8) packet symLen=16 ms, payloadSize=0, time 462 ms
DEBUG | 1 (bw=125, sf=11, cr=4/8) packet symLen=16 ms, payloadSize=253, time 7835 ms
INFO  | 1 Radio freq=433.500, config.lora.frequency_offset=0.000
INFO  | 1 Set radio: region=EU_433, name=LongMod, config=7, ch=-1, power=30
INFO  | 1 Radio myRegion->freqStart -> myRegion->freqEnd: 433.000000 -> 434.000000 (1.000000 mhz)
INFO  | 1 Radio myRegion->numChannels: 8 x 125.000kHz
INFO  | 1 Radio channel_num: 0
INFO  | 1 Radio frequency: 433.500000
INFO  | 1 Slot time: 42 msec
INFO  | 1 Set radio: final power level=22
INFO  | 1 SX126x init result 0
INFO  | 1 Frequency set to 433.500000
INFO  | 1 Bandwidth set to 125.000000
INFO  | 1 Power output set to 22
DEBUG | 1 Current limit set to 140.000000
DEBUG | 1 Current limit set result 0
DEBUG | 1 Setting DIO2 as not RF switch
DEBUG | 1 Using MCU pin -1 as RXEN and pin 13 as TXEN to control RF switching
INFO  | 1 Set RX gain to boosted mode; result: 0
INFO  | 1 SX1268 Radio init succeeded, using SX1268 radio
INFO  | 1 Not using WIFI
DEBUG | 1 (bw=125, sf=11, cr=4/8) packet symLen=16 ms, payloadSize=237, time 7376 ms
DEBUG | 1 LoRA bitrate = 32.131237 bytes / sec

Работает - принимает/передаёт, но не понятно какой мощностью, судя по логу - всего 22dB
и с пинами в логе ошибки

osmanovv, 2024-03-12:
@kpbicka could you please provide the changes you made in firmware for M33S to the community?

kpbicka, 2024-03-13:
> @kpbicka could you please provide the changes you made in firmware for M33S to the community?

Там надо всего лишь добавить
#define SX126X_MAX_POWER 22

также должна присутствовать секция
#ifdef EBYTE_E22
#define SX126X_DIO3_TCXO_VOLTAGE 1.8
#endif

до сих пор никто не знает как вообще всё это работает, но якобы SX1268 даёт 22dBm,  а дальше усилитель разгоняет до 33.

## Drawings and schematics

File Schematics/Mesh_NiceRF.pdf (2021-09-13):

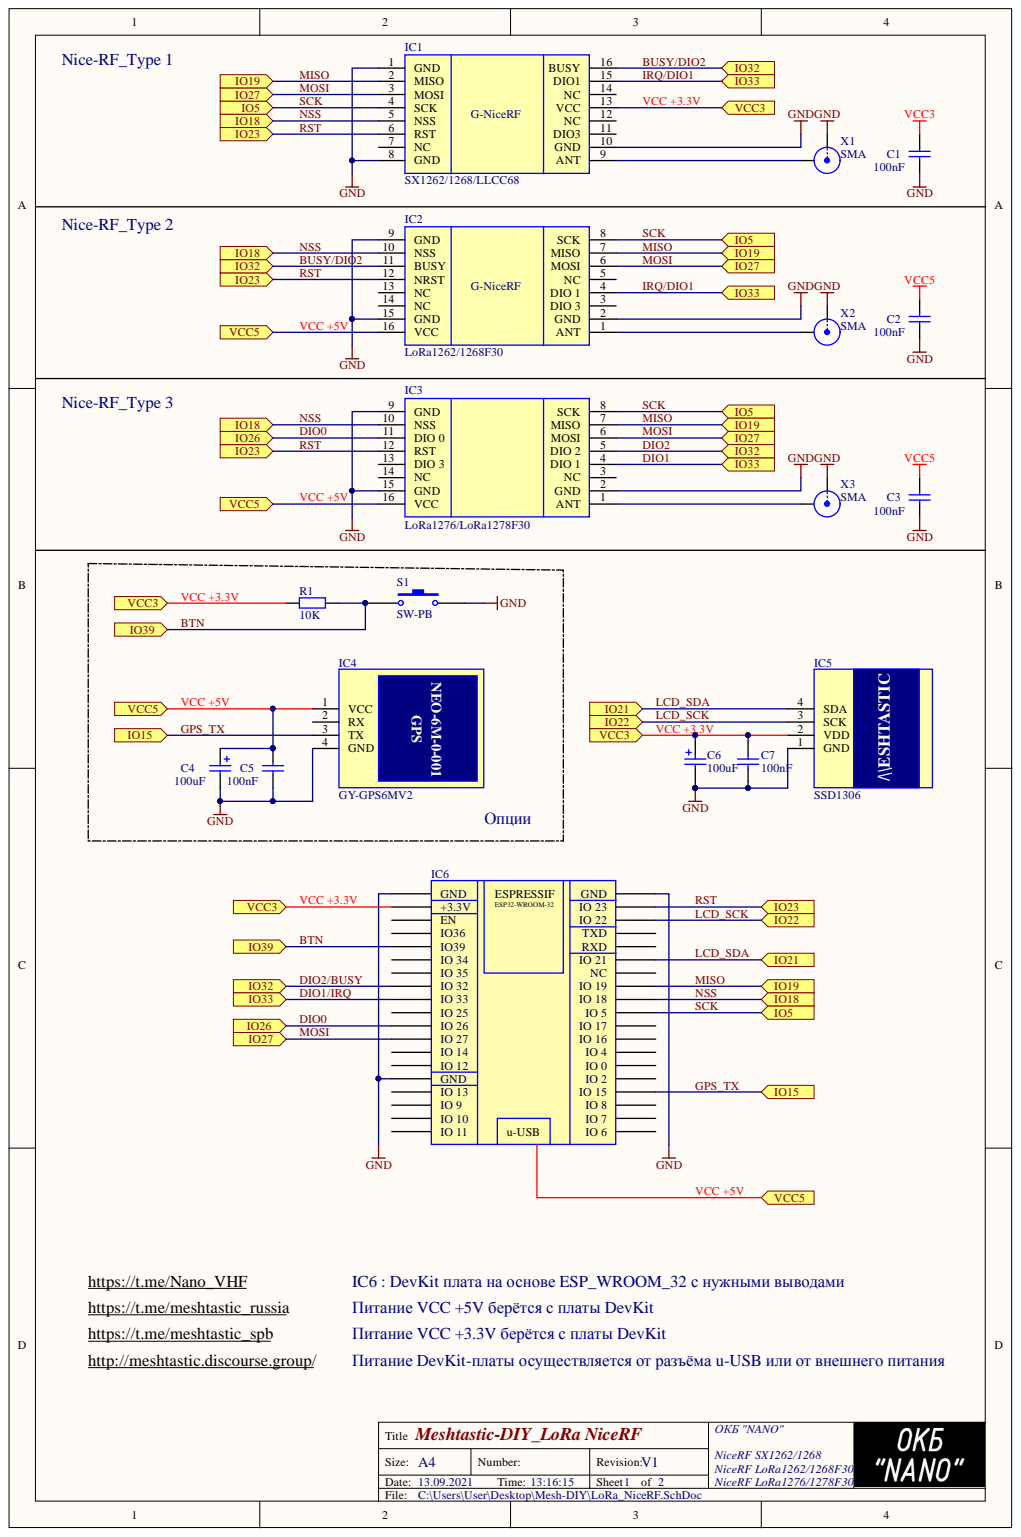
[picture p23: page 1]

GND 1 | G-NiceRF
MISO 2
MOSI 3
SCK 4
NSS 5
RST 6

ANT | 1 GND 2 DIO 3 3 DIO 1 4 NC 5 MOSI 6 MISO 7 SCK 8 GND 9
NSS 10
BUSY 11
NRST 12
NC 13

DIO 0 11
RST 12

GND | ESPRESSIF ESP32-WROOM-32 | GND
+3.3V | | IO 23 IO 22

https://t.me/Nano_VHF
https://t.me/meshtastic_russia
https://t.me/meshtastic_spb
http://meshtastic.discourse.group/

IC6 : DevKit плата на основе ESP_WROOM_32 с нужными выводами
Питание VCC +5V берётся с платы DevKit
Питание VCC +3.3V берётся с платы DevKit
Питание DevKit-платы осуществляется от разъёма u-USB или от внешнего питания

Meshtastic-DIY_LoRa NiceRF Title | ОКБ "NANO" NiceRF SX1262/1268 NiceRF LoRa1262/1268F30 NiceRF LoRa1276/1278F30

A4 Size: | Number: | V1 Revision:
Date: 13.09.2021 Time: 13:16:15 | | Sheet 1 of 2

C:\Users\User\Desktop\Mesh-DIY\LoRa_NiceRF.SchDoc

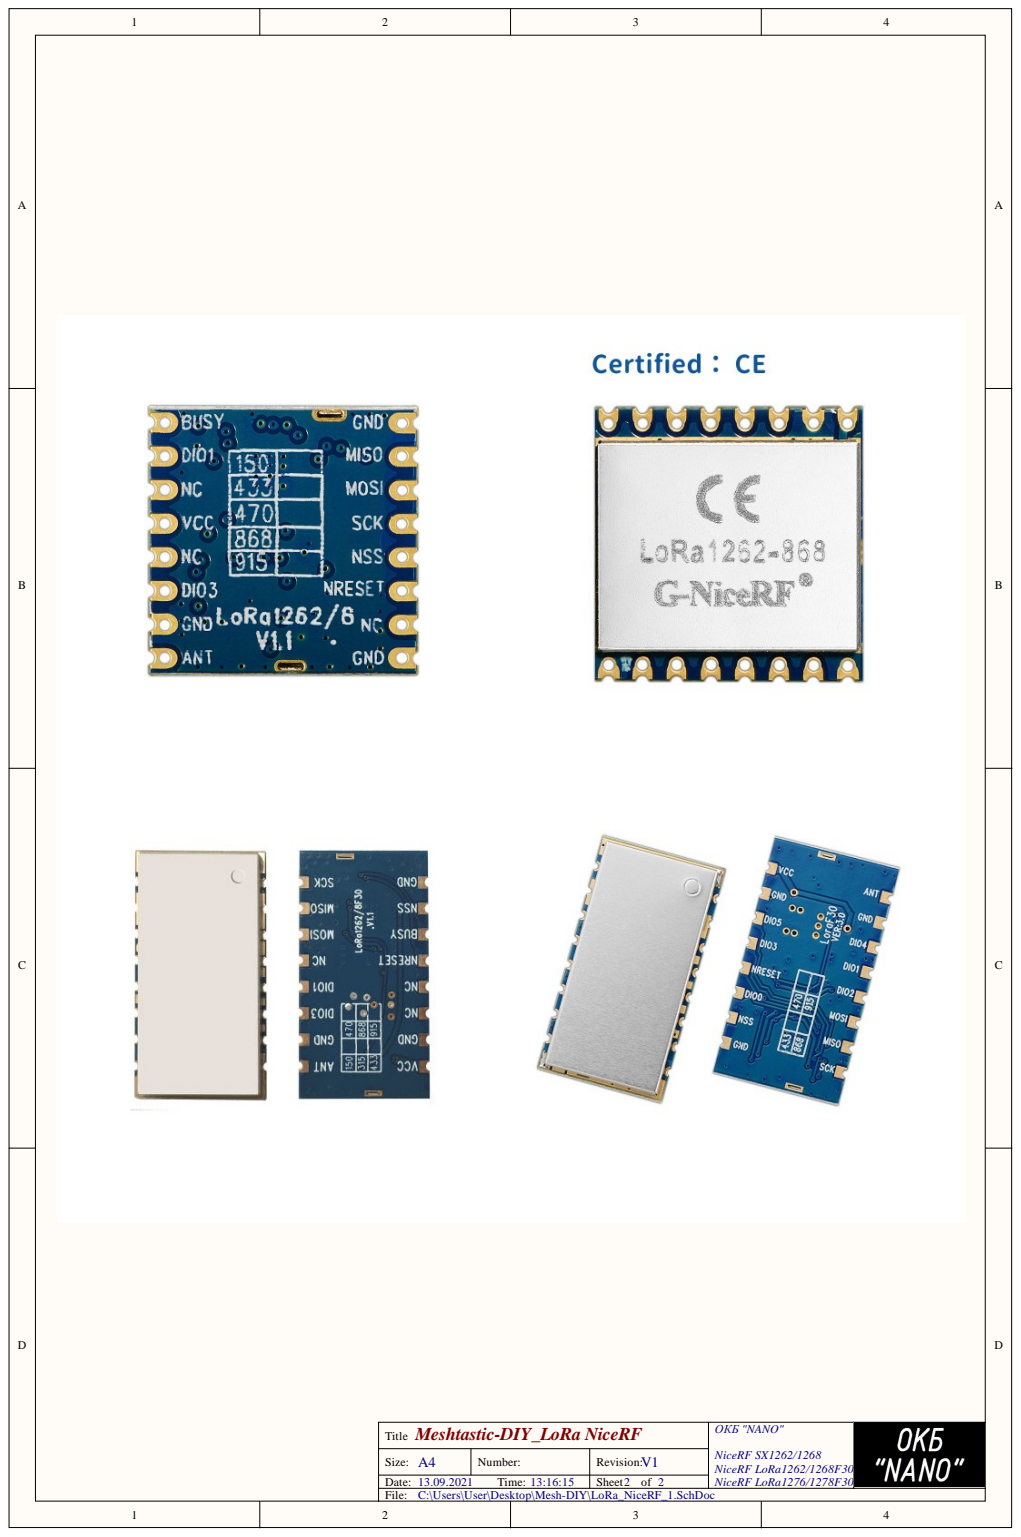
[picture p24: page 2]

Meshtastic-DIY_LoRa NiceRF Title | ОКБ "NANO" NiceRF SX1262/1268 NiceRF LoRa1262/1268F30 NiceRF LoRa1276/1278F30

A4 Size: | Number: | V1 Revision:
Date: 13.09.2021 Time: 13:16:15 | | Sheet 2 of 2

C:\Users\User\Desktop\Mesh-DIY\LoRa_NiceRF_1.SchDoc
File:

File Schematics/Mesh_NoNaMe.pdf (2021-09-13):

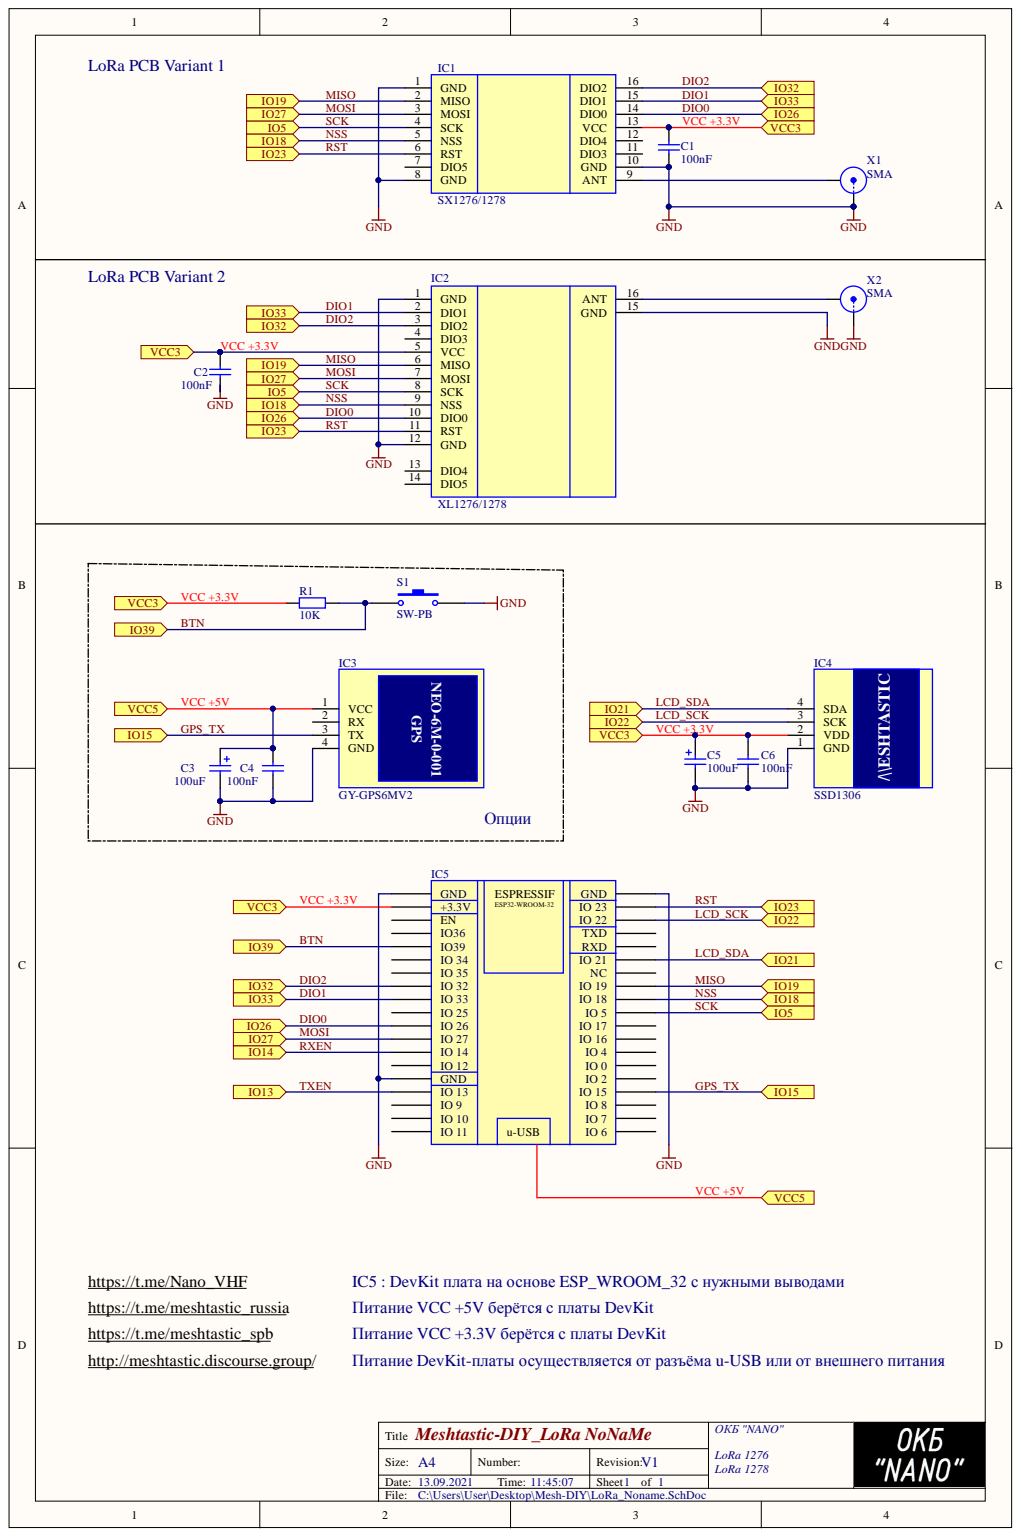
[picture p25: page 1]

GND 1
MISO 2
MOSI 3
SCK 4
NSS 5
RST 6
DIO5 7

DIO1 2
DIO2 3
DIO3 4

MOSI 7

NSS 9

RST 11

GND | ESPRESSIF ESP32-WROOM-32 | GND
+3.3V | | IO 23 IO 22

https://t.me/Nano_VHF
https://t.me/meshtastic_russia
https://t.me/meshtastic_spb
http://meshtastic.discourse.group/

IC5 : DevKit плата на основе ESP_WROOM_32 с нужными выводами
Питание VCC +5V берётся с платы DevKit
Питание VCC +3.3V берётся с платы DevKit
Питание DevKit-платы осуществляется от разъёма u-USB или от внешнего питания

Meshtastic-DIY_LoRa NoNaMe Title | ОКБ "NANO" LoRa 1276 LoRa 1278

A4 Size: | Number: | V1 Revision:
Date: 13.09.2021 Time: 11:45:07 | | Sheet 1 of 1

C:\Users\User\Desktop\Mesh-DIY\LoRa_Noname.SchDoc

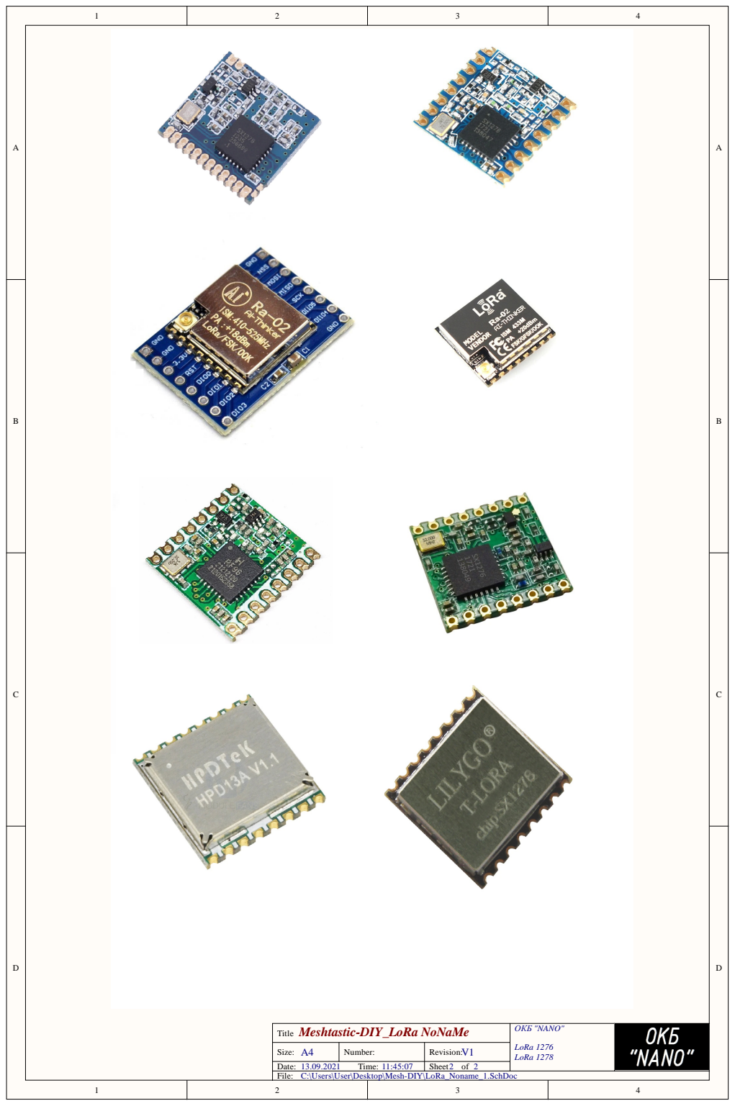
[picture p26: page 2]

Meshtastic-DIY_LoRa NoNaMe Title | ОКБ "NANO" LoRa 1276 LoRa 1278

A4 Size: | Number: | V1 Revision:
Date: 13.09.2021 Time: 11:45:07 | | Sheet 2 of 2

C:\Users\User\Desktop\Mesh-DIY\LoRa_Noname_1.SchDoc
File:

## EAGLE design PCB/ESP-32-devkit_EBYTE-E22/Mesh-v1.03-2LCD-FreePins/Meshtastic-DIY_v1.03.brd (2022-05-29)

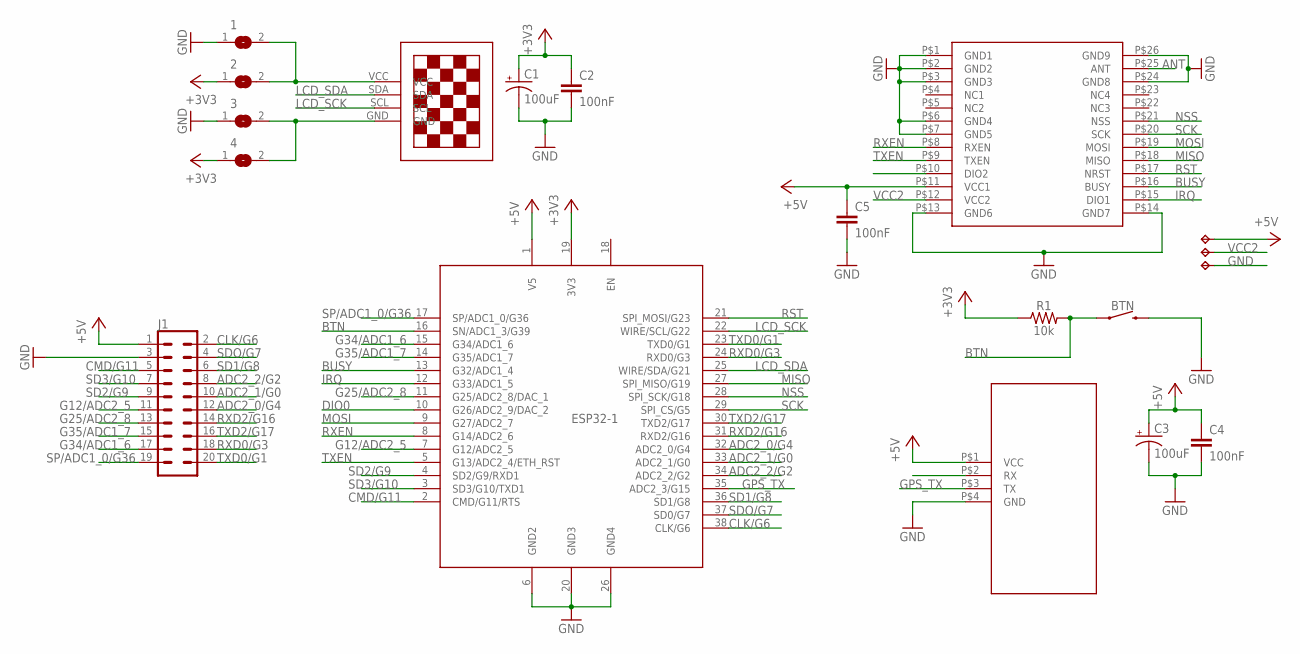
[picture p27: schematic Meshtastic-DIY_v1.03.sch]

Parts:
1, 2, 3, 4: SJ
BTN: MOMENTARY-SWITCH-SPST-SMD-5.2MM; TACTILE_SWITCH_SMD_5.2MM
C1, C3: 100uF; EIA7343
C2, C4, C5: 100nF; 0805
ESP32-1: NODEMCU_ESP32_WROOM_32; NODEMCU_ESP32_WROOM_32--38PINS
J1: CONN_10X2NOSILK; 2X10_NOSILK
R1: 10k; 1210
TP1, TP2, TP3: TPTP14SQ; TP14SQ
U$1: 13"OLED13"OLED; 1.3"OLED
U$2: E22-XXXMXXS
U$3: GPS-NEO

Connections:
+3V3: 2.1, 4.1, C1.A (+), C2.1, ESP32-1.19 (3V3), R1.1
+5V: C3.A (+), C4.1, C5.1, ESP32-1.1 (V5), J1.1, TP1.TP, U$2.P$11 (VCC1), U$3.P$1 (VCC)
ADC2_0/G4: ESP32-1.32 (ADC2_0/G4), J1.12
ADC2_1/G0: ESP32-1.33 (ADC2_1/G0), J1.10
ADC2_2/G2: ESP32-1.34 (ADC2_2/G2), J1.8
ANT: U$2.P$25 (ANT)
BTN: BTN.1, ESP32-1.16 (SN/ADC1_3/G39), R1.2
BUSY: ESP32-1.13 (G32/ADC1_4), U$2.P$16 (BUSY)
CLK/G6: ESP32-1.38 (CLK/G6), J1.2
CMD/G11: ESP32-1.2 (CMD/G11/RTS), J1.5
DIO0: ESP32-1.10 (G26/ADC2_9/DAC_2)
G12/ADC2_5: ESP32-1.7 (G12/ADC2_5), J1.11
G25/ADC2_8: ESP32-1.11 (G25/ADC2_8/DAC_1), J1.13
G34/ADC1_6: ESP32-1.15 (G34/ADC1_6), J1.17
G35/ADC1_7: ESP32-1.14 (G35/ADC1_7), J1.15
GND: 1.1, 3.1, BTN.3 (2), C1.C (-), C2.2, C3.C (-), C4.2, C5.2, ESP32-1.6 (GND2), ESP32-1.20 (GND3), ESP32-1.26 (GND4), J1.3, TP3.TP, U$2.P$1 (GND1), U$2.P$2 (GND2), U$2.P$3 (GND3), U$2.P$6 (GND4), U$2.P$7 (GND5), U$2.P$13 (GND6), U$2.P$14 (GND7), U$2.P$24 (GND8), U$2.P$26 (GND9), U$3.P$4 (GND)
GPS_TX: ESP32-1.35 (ADC2_3/G15), U$3.P$3 (TX)
IRQ: ESP32-1.12 (G33/ADC1_5), U$2.P$15 (DIO1)
LCD_SCK: ESP32-1.22 (WIRE/SCL/G22), U$1.SCL
LCD_SDA: ESP32-1.25 (WIRE/SDA/G21), U$1.SDA
MISO: ESP32-1.27 (SPI_MISO/G19), U$2.P$18 (MISO)
MOSI: ESP32-1.9 (G27/ADC2_7), U$2.P$19 (MOSI)
unnamed: 3.2, 4.2, U$1.GND
unnamed: 1.2, 2.2, U$1.VCC
NSS: ESP32-1.28 (SPI_SCK/G18), U$2.P$21 (NSS)
RST: ESP32-1.21 (SPI_MOSI/G23), U$2.P$17 (NRST)
RXD0/G3: ESP32-1.24 (RXD0/G3), J1.18
RXD2/G16: ESP32-1.31 (RXD2/G16), J1.14
RXEN: ESP32-1.8 (G14/ADC2_6), U$2.P$8 (RXEN)
SCK: ESP32-1.29 (SPI_CS/G5), U$2.P$20 (SCK)
SD1/G8: ESP32-1.36 (SD1/G8), J1.6
SD2/G9: ESP32-1.4 (SD2/G9/RXD1), J1.9
SD3/G10: ESP32-1.3 (SD3/G10/TXD1), J1.7
SDO/G7: ESP32-1.37 (SD0/G7), J1.4
SP/ADC1_0/G36: ESP32-1.17 (SP/ADC1_0/G36), J1.19
TXD0/G1: ESP32-1.23 (TXD0/G1), J1.20
TXD2/G17: ESP32-1.30 (TXD2/G17), J1.16
TXEN: ESP32-1.5 (G13/ADC2_4/ETH_RST), U$2.P$9 (TXEN)
VCC2: TP2.TP, U$2.P$12 (VCC2)

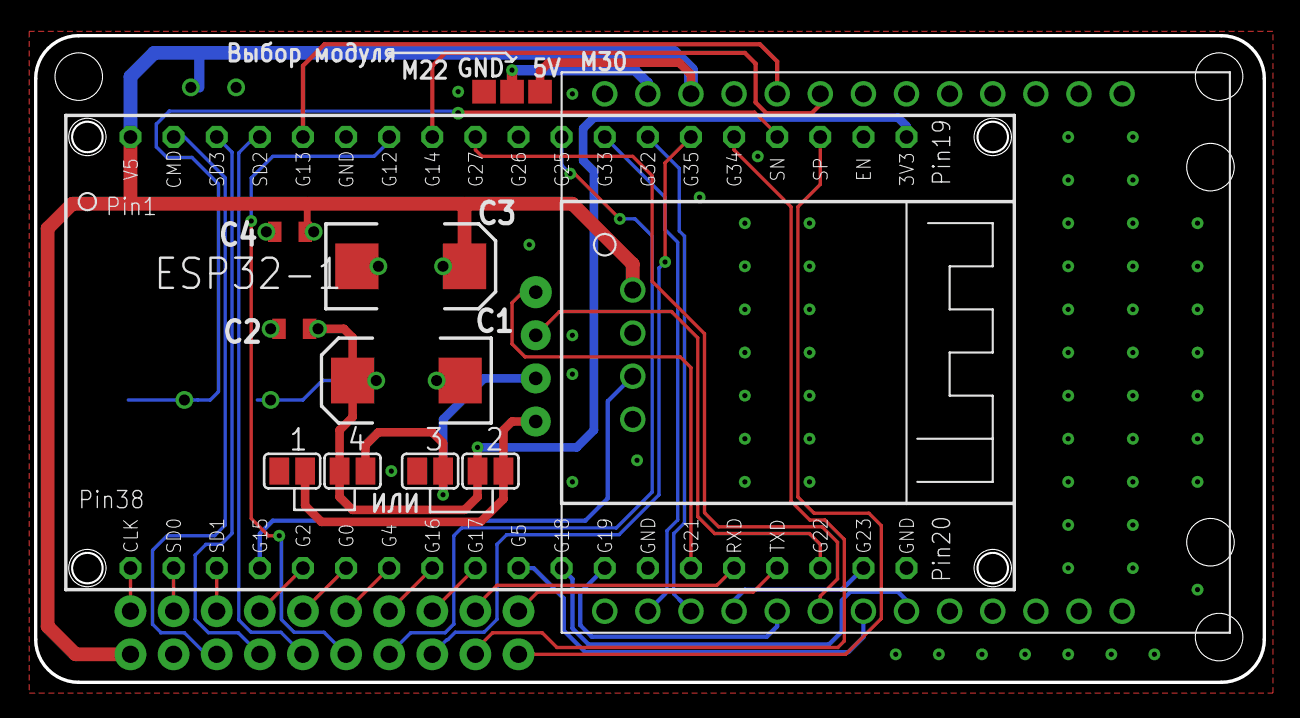
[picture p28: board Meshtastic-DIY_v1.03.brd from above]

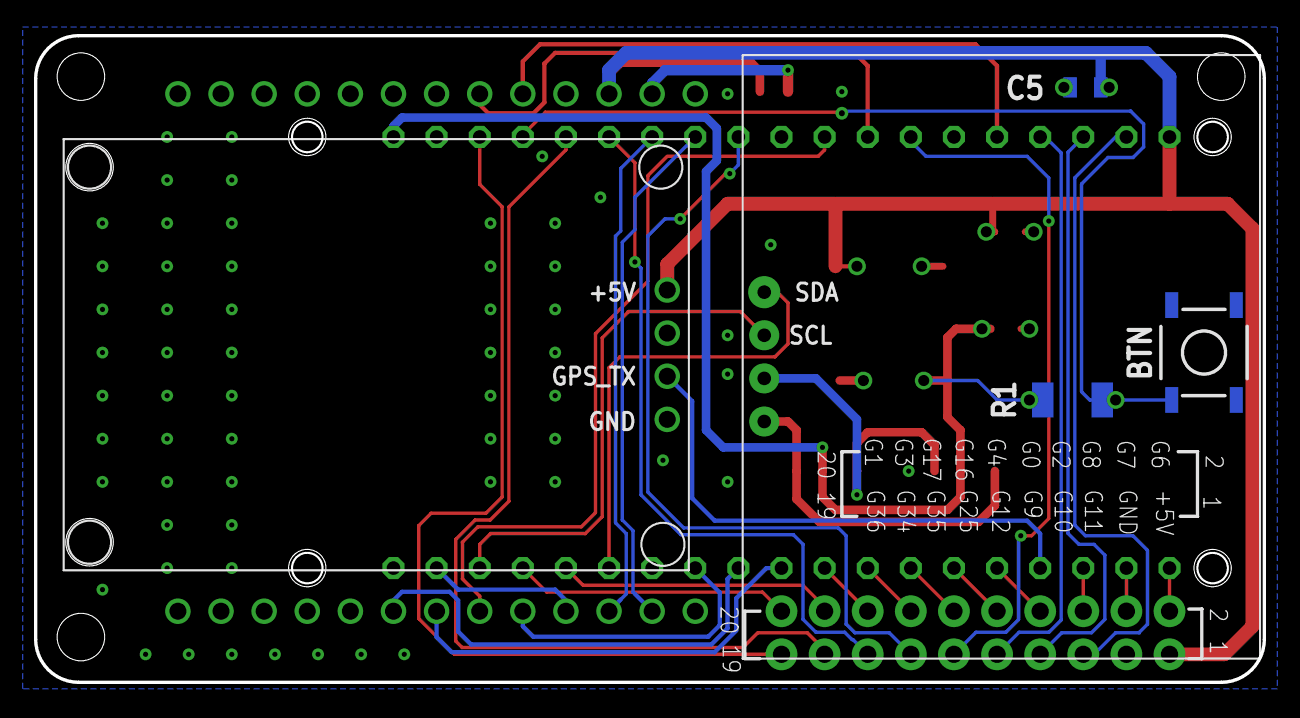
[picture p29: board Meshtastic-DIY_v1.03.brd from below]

Board: 2 copper layers, 72.4 x 38.1 mm, 19 parts (5 on the bottom side), 37 nets.

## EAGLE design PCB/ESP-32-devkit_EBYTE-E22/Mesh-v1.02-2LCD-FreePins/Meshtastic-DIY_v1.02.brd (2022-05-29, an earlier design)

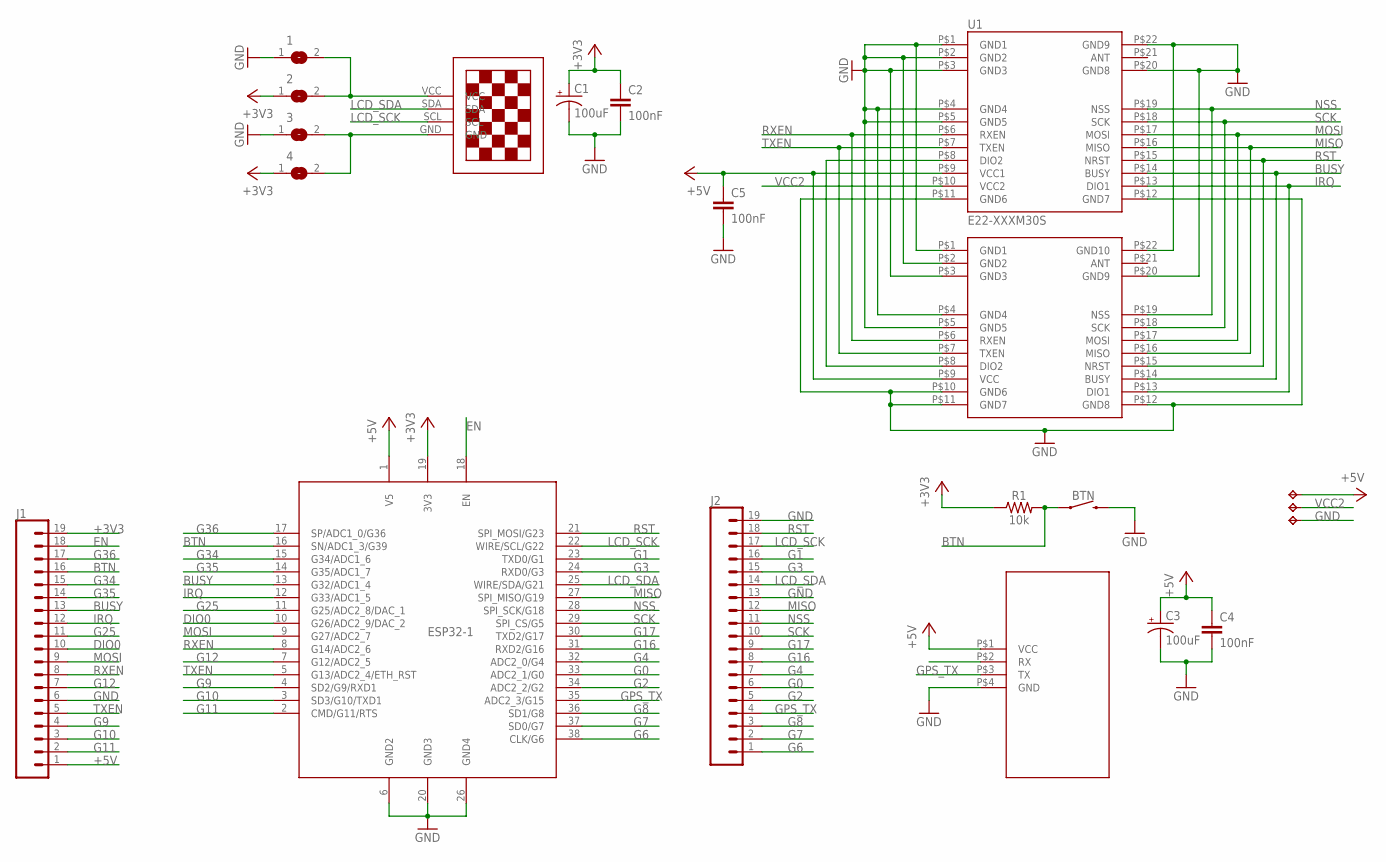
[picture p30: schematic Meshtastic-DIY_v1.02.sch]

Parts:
1, 2, 3, 4: SJ
BTN: MOMENTARY-SWITCH-SPST-PTH-6.0MM; TACTILE_SWITCH_PTH_6.0MM
C1, C3: 100uF; EIA7343
C2, C4, C5: 100nF; 0805
ESP32-1: NODEMCU_ESP32_WROOM_32; NODEMCU_ESP32_WROOM_32--38PINS
J1, J2: CONN_191X19_NO_SILK; 1X19_NO_SILK
R1: 10k; 1210
TP1, TP2, TP3: TPTP14SQ; TP14SQ
U1: E22-XXXM30S
U$1: 13"OLED13"OLED; 1.3"OLED
U$2: E22-XXXM22S
U$3: GPS-NEO

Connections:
+3V3: 2.1, 4.1, C1.A (+), C2.1, ESP32-1.19 (3V3), J1.19, R1.1
+5V: C3.A (+), C4.1, C5.1, ESP32-1.1 (V5), J1.1, TP1.TP, U1.P$9 (VCC1), U$2.P$9 (VCC), U$3.P$1 (VCC)
BTN: BTN.1, ESP32-1.16 (SN/ADC1_3/G39), J1.16, R1.2
BUSY: ESP32-1.13 (G32/ADC1_4), J1.13, U1.P$14 (BUSY), U$2.P$14 (BUSY)
DIO0: ESP32-1.10 (G26/ADC2_9/DAC_2), J1.10
EN: ESP32-1.18 (EN), J1.18
G0: ESP32-1.33 (ADC2_1/G0), J2.6
G1: ESP32-1.23 (TXD0/G1), J2.16
G2: ESP32-1.34 (ADC2_2/G2), J2.5
G3: ESP32-1.24 (RXD0/G3), J2.15
G4: ESP32-1.32 (ADC2_0/G4), J2.7
G6: ESP32-1.38 (CLK/G6), J2.1
G7: ESP32-1.37 (SD0/G7), J2.2
G8: ESP32-1.36 (SD1/G8), J2.3
G9: ESP32-1.4 (SD2/G9/RXD1), J1.4
G10: ESP32-1.3 (SD3/G10/TXD1), J1.3
G11: ESP32-1.2 (CMD/G11/RTS), J1.2
G12: ESP32-1.7 (G12/ADC2_5), J1.7
G16: ESP32-1.31 (RXD2/G16), J2.8
G17: ESP32-1.30 (TXD2/G17), J2.9
G25: ESP32-1.11 (G25/ADC2_8/DAC_1), J1.11
G34: ESP32-1.15 (G34/ADC1_6), J1.15
G35: ESP32-1.14 (G35/ADC1_7), J1.14
G36: ESP32-1.17 (SP/ADC1_0/G36), J1.17
GND: 1.1, 3.1, BTN.3 (2), C1.C (-), C2.2, C3.C (-), C4.2, C5.2, ESP32-1.6 (GND2), ESP32-1.20 (GND3), ESP32-1.26 (GND4), J1.6, J2.13, J2.19, TP3.TP, U1.P$1 (GND1), U1.P$2 (GND2), U1.P$3 (GND3), U1.P$4 (GND4), U1.P$5 (GND5), U1.P$11 (GND6), U1.P$12 (GND7), U1.P$20 (GND8), U1.P$22 (GND9), U$2.P$1 (GND1), U$2.P$2 (GND2), U$2.P$3 (GND3), U$2.P$4 (GND4), U$2.P$5 (GND5), U$2.P$10 (GND6), U$2.P$11 (GND7), U$2.P$12 (GND8), U$2.P$20 (GND9), U$2.P$22 (GND10), U$3.P$4 (GND)
GPS_TX: ESP32-1.35 (ADC2_3/G15), J2.4, U$3.P$3 (TX)
IRQ: ESP32-1.12 (G33/ADC1_5), J1.12, U1.P$13 (DIO1), U$2.P$13 (DIO1)
LCD_SCK: ESP32-1.22 (WIRE/SCL/G22), J2.17, U$1.SCL
LCD_SDA: ESP32-1.25 (WIRE/SDA/G21), J2.14, U$1.SDA
MISO: ESP32-1.27 (SPI_MISO/G19), J2.12, U1.P$16 (MISO), U$2.P$16 (MISO)
MOSI: ESP32-1.9 (G27/ADC2_7), J1.9, U1.P$17 (MOSI), U$2.P$17 (MOSI)
unnamed: 3.2, 4.2, U$1.GND
unnamed: 1.2, 2.2, U$1.VCC
unnamed: U1.P$8 (DIO2), U$2.P$8 (DIO2)
NSS: ESP32-1.28 (SPI_SCK/G18), J2.11, U1.P$19 (NSS), U$2.P$19 (NSS)
RST: ESP32-1.21 (SPI_MOSI/G23), J2.18, U1.P$15 (NRST), U$2.P$15 (NRST)
RXEN: ESP32-1.8 (G14/ADC2_6), J1.8, U1.P$6 (RXEN), U$2.P$6 (RXEN)
SCK: ESP32-1.29 (SPI_CS/G5), J2.10, U1.P$18 (SCK), U$2.P$18 (SCK)
TXEN: ESP32-1.5 (G13/ADC2_4/ETH_RST), J1.5, U1.P$7 (TXEN), U$2.P$7 (TXEN)
VCC2: TP2.TP, U1.P$10 (VCC2)

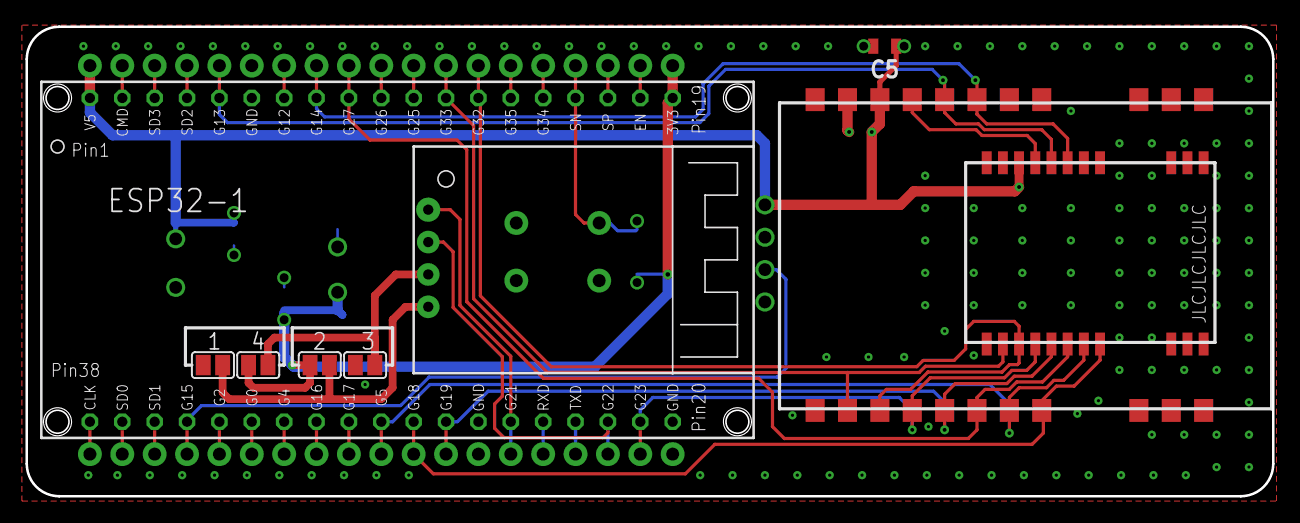
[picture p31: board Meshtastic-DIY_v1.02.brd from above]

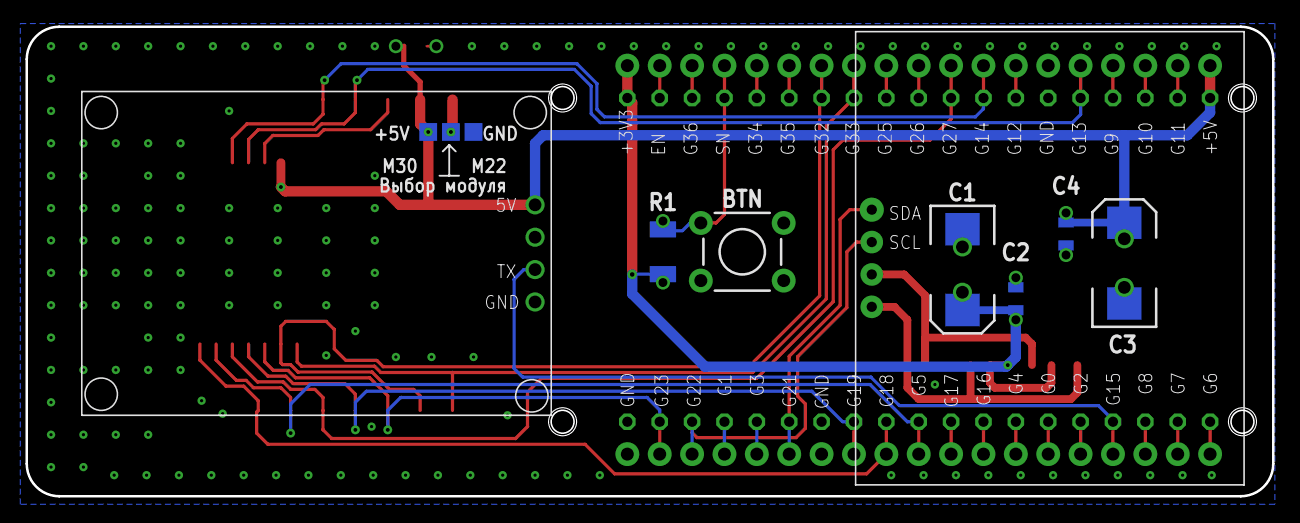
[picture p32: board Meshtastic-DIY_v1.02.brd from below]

Board: 2 copper layers, 97.8 x 36.8 mm, 21 parts (11 on the bottom side), 40 nets.

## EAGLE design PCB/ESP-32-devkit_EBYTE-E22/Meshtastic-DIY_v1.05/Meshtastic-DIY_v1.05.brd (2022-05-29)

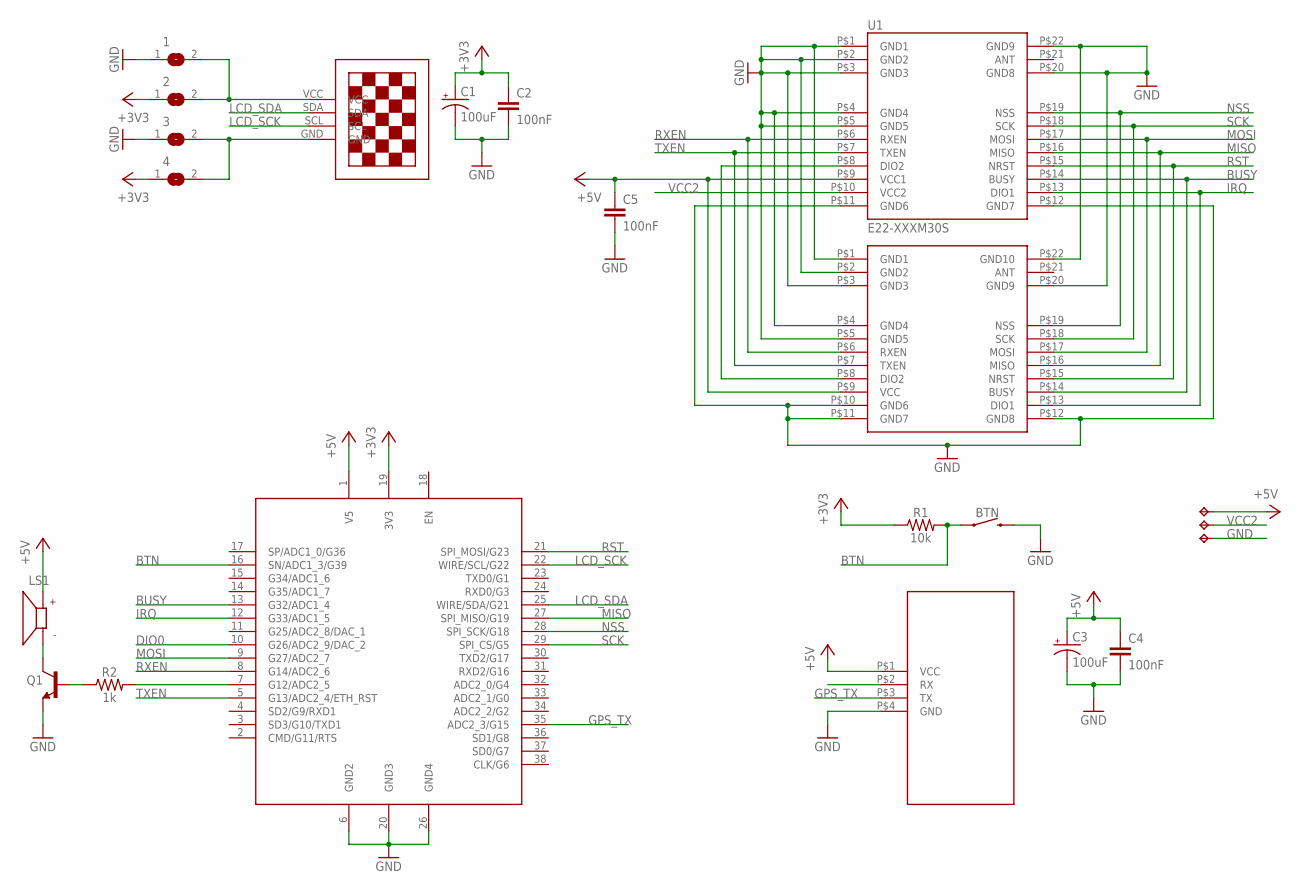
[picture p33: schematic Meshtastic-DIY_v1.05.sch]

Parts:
1, 2, 3, 4: SJ
BTN: MOMENTARY-SWITCH-SPST-PTH-6.0MM; TACTILE_SWITCH_PTH_6.0MM
C1, C3: 100uF; CPOL-RADIAL-2.5MM-6.5MM
C2, C4, C5: 100nF; 0805
ESP32-1: NODEMCU_ESP32_WROOM_32; NODEMCU_ESP32_WROOM_32--38PINS
LS1: CMT-0926-86-SMT-TR; XDCR_CMT-0926-86-SMT-TR
Q1: 200mA/40V; TO-92
R1: 10k; 1210
R2: 1k; 1210
TP1, TP2, TP3: TPTP14SQ; TP14SQ
U1: E22-XXXM30S
U$1: 13"OLED13"OLED; 1.3"OLED
U$2: E22-XXXM22S
U$3: GPS-NEO

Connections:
+3V3: 2.1, 4.1, C1.1 (+), C2.1, ESP32-1.19 (3V3), R1.1
+5V: C3.1 (+), C4.1, C5.1, ESP32-1.1 (V5), LS1.P, TP1.TP, U1.P$9 (VCC1), U$2.P$9 (VCC), U$3.P$1 (VCC)
BTN: BTN.1, ESP32-1.16 (SN/ADC1_3/G39), R1.2
BUSY: ESP32-1.13 (G32/ADC1_4), U1.P$14 (BUSY), U$2.P$14 (BUSY)
CMD/G11/RTS: ESP32-1.2 (CMD/G11/RTS)
DIO0: ESP32-1.10 (G26/ADC2_9/DAC_2)
GND: 1.1, 3.1, BTN.3 (2), C1.2 (-), C2.2, C3.2 (-), C4.2, C5.2, ESP32-1.6 (GND2), ESP32-1.20 (GND3), ESP32-1.26 (GND4), Q1.1 (E), TP3.TP, U1.P$1 (GND1), U1.P$2 (GND2), U1.P$3 (GND3), U1.P$4 (GND4), U1.P$5 (GND5), U1.P$11 (GND6), U1.P$12 (GND7), U1.P$20 (GND8), U1.P$22 (GND9), U$2.P$1 (GND1), U$2.P$2 (GND2), U$2.P$3 (GND3), U$2.P$4 (GND4), U$2.P$5 (GND5), U$2.P$10 (GND6), U$2.P$11 (GND7), U$2.P$12 (GND8), U$2.P$20 (GND9), U$2.P$22 (GND10), U$3.P$4 (GND)
GPS_TX: ESP32-1.35 (ADC2_3/G15), U$3.P$3 (TX)
IRQ: ESP32-1.12 (G33/ADC1_5), U1.P$13 (DIO1), U$2.P$13 (DIO1)
LCD_SCK: ESP32-1.22 (WIRE/SCL/G22), U$1.SCL
LCD_SDA: ESP32-1.25 (WIRE/SDA/G21), U$1.SDA
MISO: ESP32-1.27 (SPI_MISO/G19), U1.P$16 (MISO), U$2.P$16 (MISO)
MOSI: ESP32-1.9 (G27/ADC2_7), U1.P$17 (MOSI), U$2.P$17 (MOSI)
unnamed: 1.2, 2.2, U$1.VCC
unnamed: 3.2, 4.2, U$1.GND
unnamed: LS1.N, Q1.3 (C)
unnamed: ESP32-1.7 (G12/ADC2_5), R2.2
unnamed: Q1.2 (B), R2.1
unnamed: U1.P$8 (DIO2), U$2.P$8 (DIO2)
NSS: ESP32-1.28 (SPI_SCK/G18), U1.P$19 (NSS), U$2.P$19 (NSS)
RST: ESP32-1.21 (SPI_MOSI/G23), U1.P$15 (NRST), U$2.P$15 (NRST)
RXEN: ESP32-1.8 (G14/ADC2_6), U1.P$6 (RXEN), U$2.P$6 (RXEN)
SCK: ESP32-1.29 (SPI_CS/G5), U1.P$18 (SCK), U$2.P$18 (SCK)
TXEN: ESP32-1.5 (G13/ADC2_4/ETH_RST), U1.P$7 (TXEN), U$2.P$7 (TXEN)
VCC2: TP2.TP, U1.P$10 (VCC2)

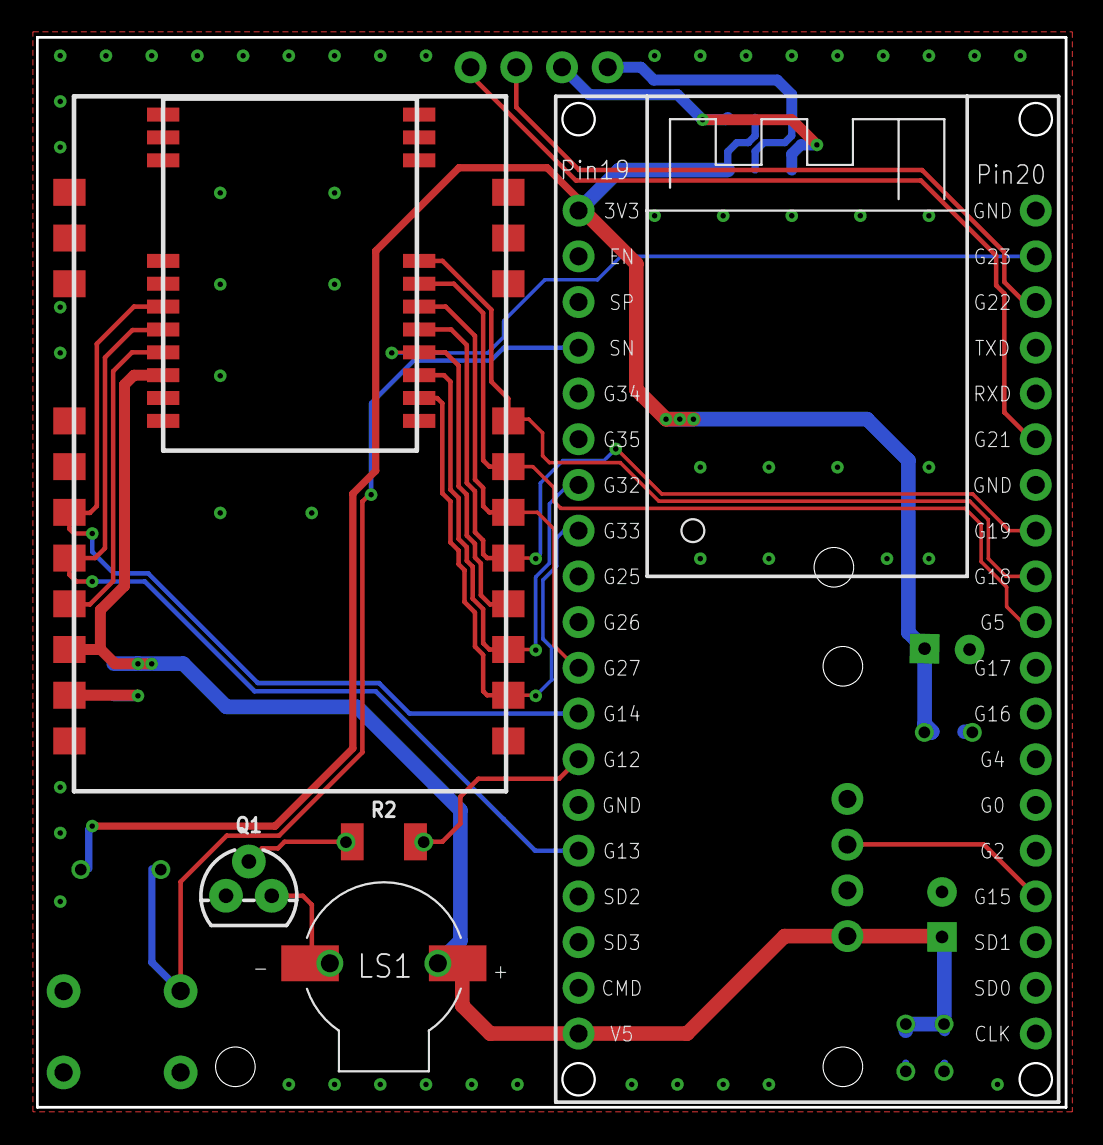
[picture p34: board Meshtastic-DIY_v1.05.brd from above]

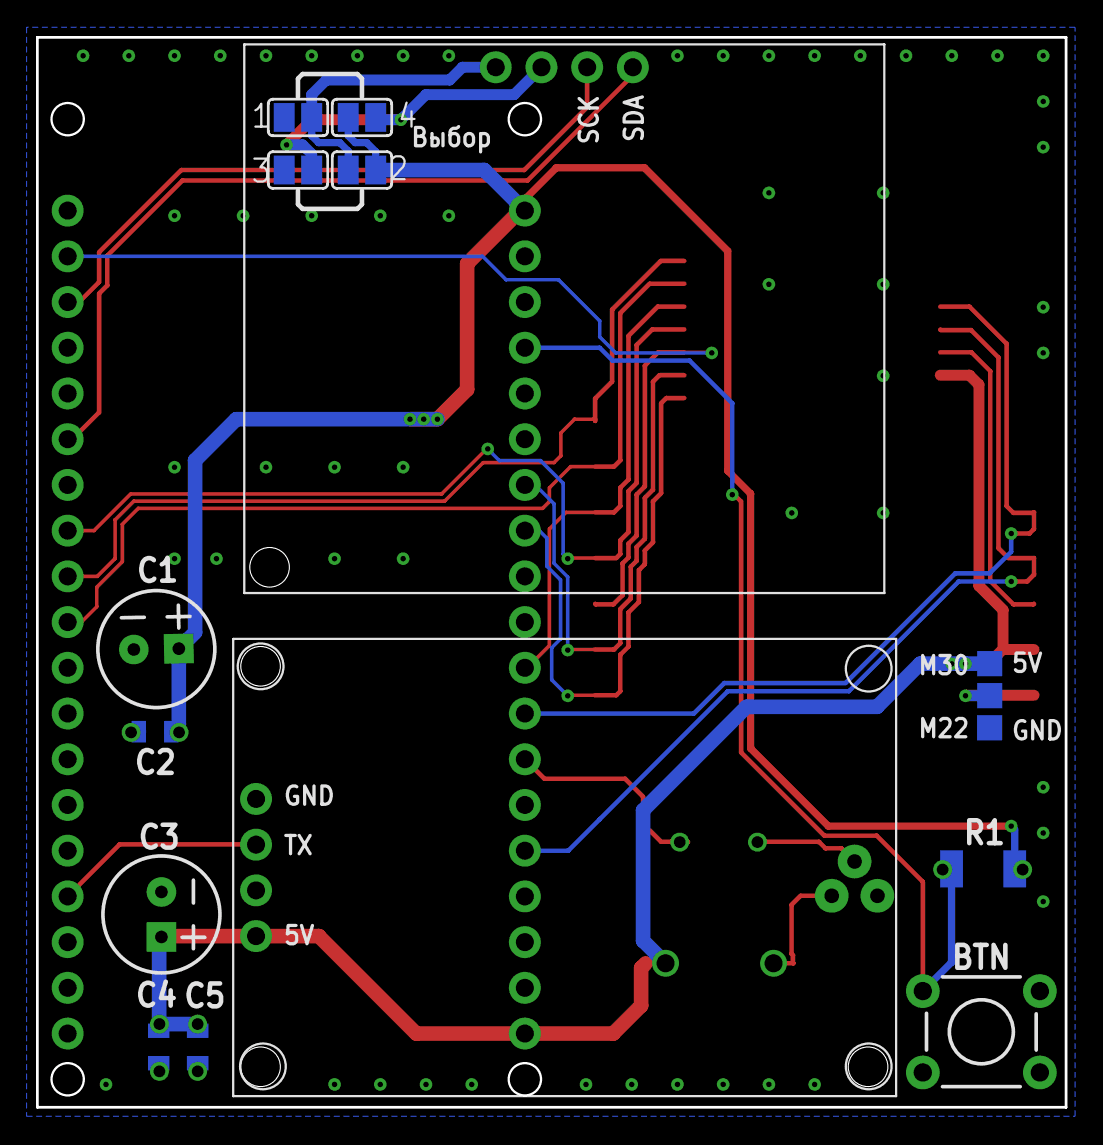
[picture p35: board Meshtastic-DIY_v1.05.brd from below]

Board: 2 copper layers, 57.1 x 59.4 mm, 22 parts (16 on the bottom side), 23 nets.

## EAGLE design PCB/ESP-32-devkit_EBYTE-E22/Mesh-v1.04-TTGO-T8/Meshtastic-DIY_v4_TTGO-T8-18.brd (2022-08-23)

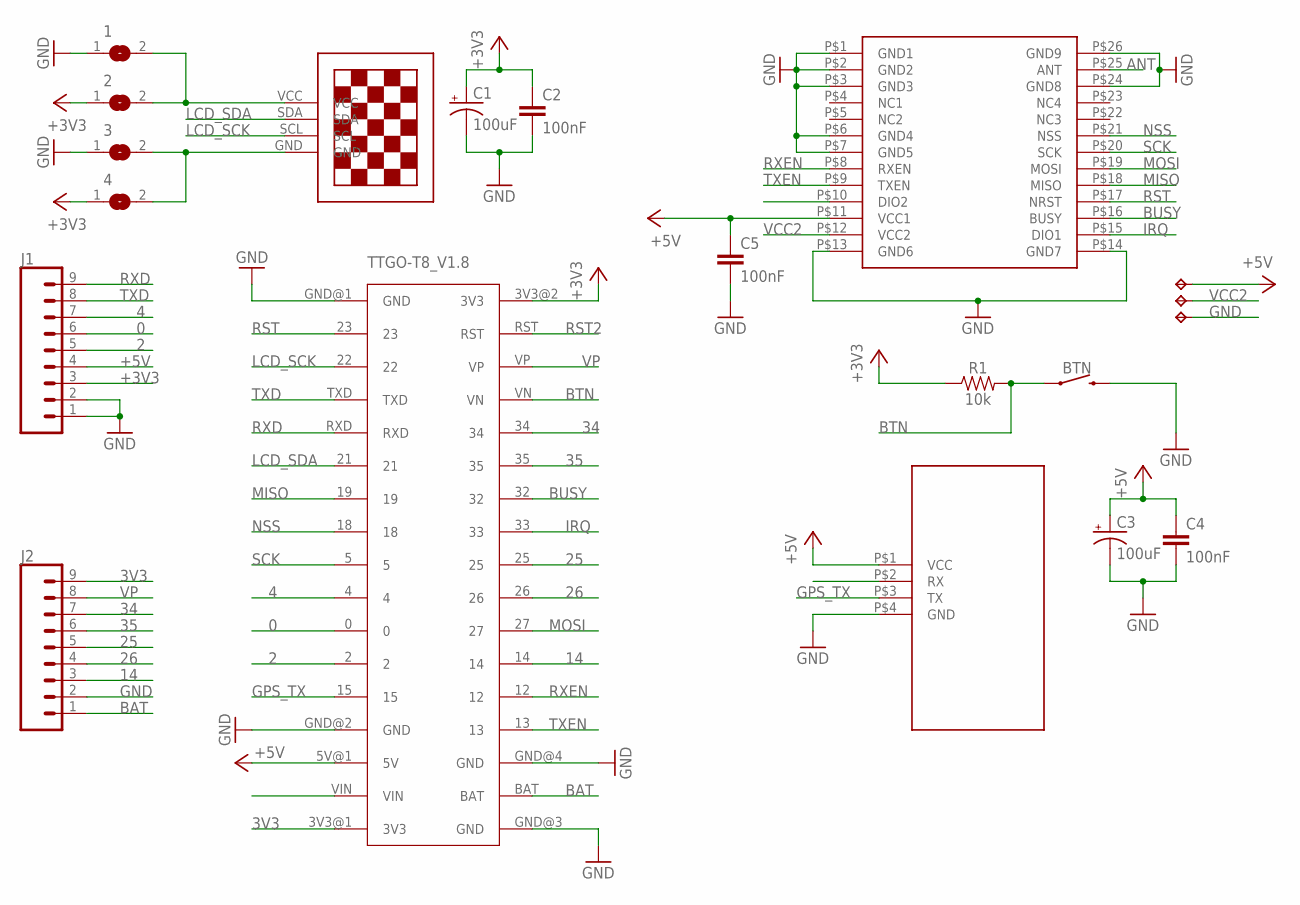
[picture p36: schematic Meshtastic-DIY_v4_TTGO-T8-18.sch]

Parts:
1, 2, 3, 4: SJ
BTN: MOMENTARY-SWITCH-SPST-SMD-5.2MM; TACTILE_SWITCH_SMD_5.2MM
C1, C3: 100uF; EIA7343
C2, C4, C5: 100nF; 0805
J1, J2: CONN_09NO_SILK; 1X09_NO_SILK
R1: 10k; 1210
TP1, TP2, TP3: TPTP14SQ; TP14SQ
TTGO-T8_V1.8: TTGO-T8_V18
U$1: 13"OLED13"OLED; 1.3"OLED
U$2: E22-XXXMXXS
U$3: GPS-NEO

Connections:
0: J1.6, TTGO-T8_V1.8.0
2: J1.5, TTGO-T8_V1.8.2
3V3: J2.9, TTGO-T8_V1.8.3V3@1 (3V3)
4: J1.7, TTGO-T8_V1.8.4
14: J2.3, TTGO-T8_V1.8.14
25: J2.5, TTGO-T8_V1.8.25
26: J2.4, TTGO-T8_V1.8.26
34: J2.7, TTGO-T8_V1.8.34
35: J2.6, TTGO-T8_V1.8.35
+3V3: 2.1, 4.1, C1.A (+), C2.1, J1.3, R1.1, TTGO-T8_V1.8.3V3@2 (3V3)
+5V: C3.A (+), C4.1, C5.1, J1.4, TP1.TP, TTGO-T8_V1.8.5V@1 (5V), U$2.P$11 (VCC1), U$3.P$1 (VCC)
ANT: U$2.P$25 (ANT)
BAT: J2.1, TTGO-T8_V1.8.BAT
BTN: BTN.1, R1.2, TTGO-T8_V1.8.VN
BUSY: TTGO-T8_V1.8.32, U$2.P$16 (BUSY)
GND: 1.1, 3.1, BTN.3 (2), C1.C (-), C2.2, C3.C (-), C4.2, C5.2, J1.1, J1.2, J2.2, TP3.TP, TTGO-T8_V1.8.GND@1 (GND), TTGO-T8_V1.8.GND@2 (GND), TTGO-T8_V1.8.GND@3 (GND), TTGO-T8_V1.8.GND@4 (GND), U$2.P$1 (GND1), U$2.P$2 (GND2), U$2.P$3 (GND3), U$2.P$6 (GND4), U$2.P$7 (GND5), U$2.P$13 (GND6), U$2.P$14 (GND7), U$2.P$24 (GND8), U$2.P$26 (GND9), U$3.P$4 (GND)
GPS_TX: TTGO-T8_V1.8.15, U$3.P$3 (TX)
IRQ: TTGO-T8_V1.8.33, U$2.P$15 (DIO1)
LCD_SCK: TTGO-T8_V1.8.22, U$1.SCL
LCD_SDA: TTGO-T8_V1.8.21, U$1.SDA
MISO: TTGO-T8_V1.8.19, U$2.P$18 (MISO)
MOSI: TTGO-T8_V1.8.27, U$2.P$19 (MOSI)
unnamed: 3.2, 4.2, U$1.GND
unnamed: 1.2, 2.2, U$1.VCC
NSS: TTGO-T8_V1.8.18, U$2.P$21 (NSS)
RST: TTGO-T8_V1.8.23, U$2.P$17 (NRST)
RST2: TTGO-T8_V1.8.RST
RXD: J1.9, TTGO-T8_V1.8.RXD
RXEN: TTGO-T8_V1.8.12, U$2.P$8 (RXEN)
SCK: TTGO-T8_V1.8.5, U$2.P$20 (SCK)
TXD: J1.8, TTGO-T8_V1.8.TXD
TXEN: TTGO-T8_V1.8.13, U$2.P$9 (TXEN)
VCC2: TP2.TP, U$2.P$12 (VCC2)
VP: J2.8, TTGO-T8_V1.8.VP

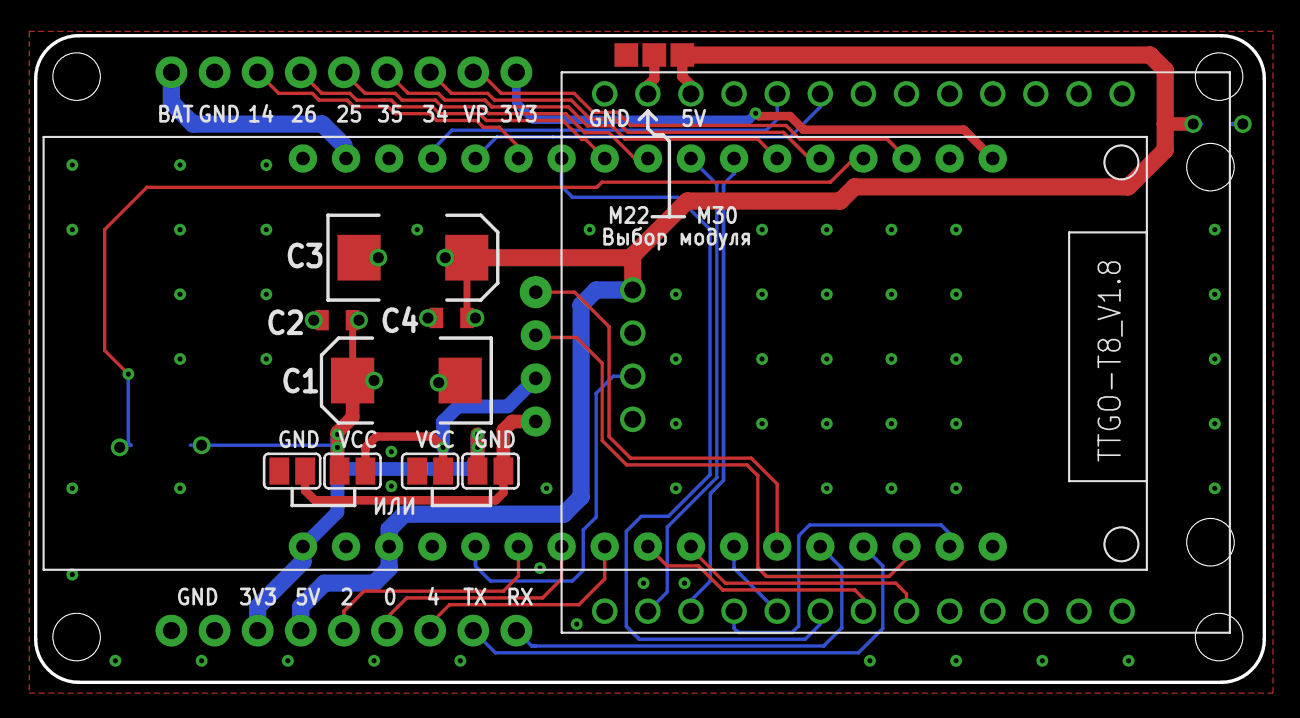
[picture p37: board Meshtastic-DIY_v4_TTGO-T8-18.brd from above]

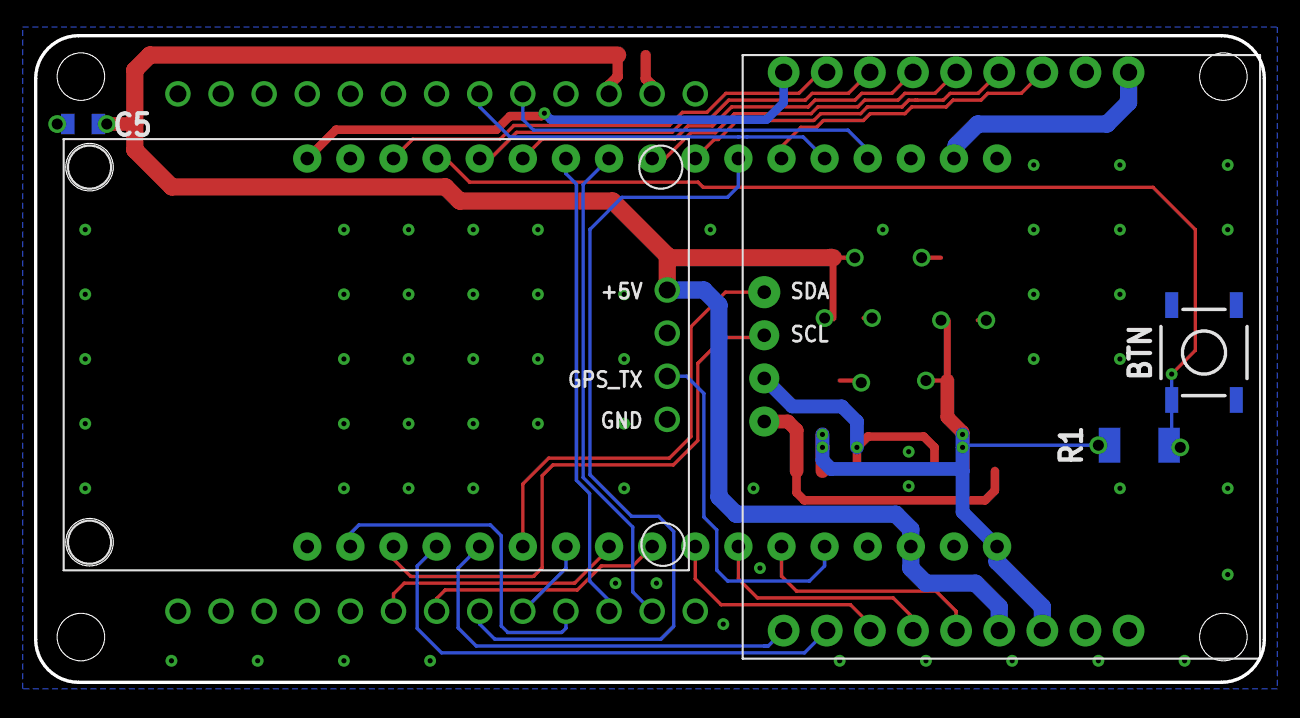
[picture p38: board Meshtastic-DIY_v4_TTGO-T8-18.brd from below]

Board: 2 copper layers, 72.4 x 38.1 mm, 20 parts (5 on the bottom side), 32 nets.

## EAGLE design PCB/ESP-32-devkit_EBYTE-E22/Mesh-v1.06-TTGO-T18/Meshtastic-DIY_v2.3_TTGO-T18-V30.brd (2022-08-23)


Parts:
3V3, 3V3.: SJ
BTN: MOMENTARY-SWITCH-SPST-SMD-5.2MM; TACTILE_SWITCH_SMD_5.2MM
C1, C3: 100uF; EIA7343
C2, C4, C6: 100nF; C025-024X044
GND, GND.: SJ
R1: 1k; AXIAL-0.1
TP1, TP2, TP3: TPTP14SQ; TP14SQ
U$1: 13"OLED13"OLED; 1.3"OLED
U$2: E22-XXXMXXS
U$4: TTGO-T18_V3

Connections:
+3V3: 3V3.1, 3V3..1, C1.A (+), C2.1, R1.P$1 (1), U$4.3V3
+5V: C3.A (+), C4.1, C6.1, TP1.TP, U$2.P$11 (VCC1), U$4.5V
BTN: BTN.1, R1.P$2 (2), U$4.39
BUSY: U$2.P$16 (BUSY), U$4.32
GND: BTN.3 (2), C1.C (-), C2.2, C3.C (-), C4.2, C6.2, GND.1, GND..1, TP3.TP, U$2.P$1 (GND1), U$2.P$2 (GND2), U$2.P$3 (GND3), U$2.P$6 (GND4), U$2.P$7 (GND5), U$2.P$13 (GND6), U$2.P$14 (GND7), U$2.P$24 (GND8), U$2.P$26 (GND9), U$4.GND1, U$4.GND2, U$4.GND3
IRQ: U$2.P$15 (DIO1), U$4.33
LCD_SCL: U$1.SCL, U$4.22
LCD_SDA: U$1.SDA, U$4.21
MISO: U$2.P$18 (MISO), U$4.19
MOSI: U$2.P$19 (MOSI), U$4.27
unnamed: 3V3.2, GND..2, U$1.GND
unnamed: 3V3..2, GND.2, U$1.VCC
NSS: U$2.P$21 (NSS), U$4.18
RST: U$2.P$17 (NRST), U$4.23
RXD: U$4.RX/3
RXEN: U$2.P$8 (RXEN), U$4.14
SCK: U$2.P$20 (SCK), U$4.5
TXD: U$4.TX/1
TXEN: U$2.P$9 (TXEN), U$4.13
VCC2: TP2.TP, U$2.P$12 (VCC2)


Board: 2 copper layers, 91.4 x 36.2 mm, 17 parts (1 on the bottom side), 18 nets.

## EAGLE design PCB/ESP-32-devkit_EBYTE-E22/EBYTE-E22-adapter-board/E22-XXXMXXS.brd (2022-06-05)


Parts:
J1, J2, J3, J4: CONN_13; 1X13
U1: E22-XXXM30S
U$1: E22-XXXM22S

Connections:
ANT: J2.2, J4.2, U1.P$21 (ANT), U$1.P$21 (ANT)
BUSY: J2.11, J4.11, U1.P$14 (BUSY), U$1.P$14 (BUSY)
DIO1: J2.12, J4.12, U1.P$13 (DIO1), U$1.P$13 (DIO1)
DIO2: J1.4, J3.4, U1.P$8 (DIO2), U$1.P$8 (DIO2)
GND: J1.1, J1.11, J1.12, J1.13, J2.1, J2.3, J2.13, J3.1, J3.7, J3.8, J3.11, J3.12, J3.13, J4.1, J4.3, J4.13, U1.P$1 (GND1), U1.P$2 (GND2), U1.P$3 (GND3), U1.P$11 (GND6), U1.P$12 (GND7), U1.P$20 (GND8), U1.P$22 (GND9), U$1.P$1 (GND1), U$1.P$2 (GND2), U$1.P$3 (GND3), U$1.P$10 (GND6), U$1.P$11 (GND7), U$1.P$12 (GND8), U$1.P$20 (GND9), U$1.P$22 (GND10)
GND4: J1.8, U1.P$4 (GND4), U$1.P$4 (GND4)
GND5: J1.7, U1.P$5 (GND5), U$1.P$5 (GND5)
MISO: J2.9, J4.9, U1.P$16 (MISO), U$1.P$16 (MISO)
MOSI: J2.8, J4.8, U1.P$17 (MOSI), U$1.P$17 (MOSI)
NRST: J2.10, J4.10, U1.P$15 (NRST), U$1.P$15 (NRST)
NSS: J2.6, J4.6, U1.P$19 (NSS), U$1.P$19 (NSS)
RXEN: J1.6, J3.6, U1.P$6 (RXEN), U$1.P$6 (RXEN)
SCK: J2.7, J4.7, U1.P$18 (SCK), U$1.P$18 (SCK)
TXEN: J1.5, J3.5, U1.P$7 (TXEN), U$1.P$7 (TXEN)
VCC1: J1.3, J3.3, U1.P$9 (VCC1), U$1.P$9 (VCC)
VCC2: J1.2, J3.2, U1.P$10 (VCC2)


Board: 2 copper layers, 32.9 x 38.9 mm, 6 parts (0 on the bottom side), 16 nets.

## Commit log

2021-09-10 Add schematic E19 modules
2021-09-10 soldering instruction howto
2021-09-16 Add 3el antenna device
2021-09-28 Commercial antennas (#8)
    * First commit, testing
    * Update Links.md
    * Update Links.md
    Add links
    * Update Links.md
    * Add common links into Links.md
    * Update Links.md
    Fix typo
    * Create FAQ_ru.md
    * First version of FAQ_ru.md, scratch
    * Add links into Links.md
    * Modify FAQ_ru.md
    * Add link into FAQ_ru.md
    * Add Ebyte TX868-XPL-100 antenna
    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
    [INNO-868-19WM.csv, TX433-XPL-100.csv, TX868-XPL-100.csv]
2021-09-28 Применение МШУ
2021-10-08 Fixed bug GPS
    Fixed bug with pin RX GPS.
2021-10-09 Edited Docs/README and Docs/FAQ_ru (#9)
    * Add info into Ebyte_TX868-XPL-100.md
    * Add Ebyte TX433-XPL-100 antenna
    * Add INNO-868-19WM antenna and data files
    * Update README.md
    * Edit FAQ and README
    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
2021-12-14 Initial PCB design for ESP32 WROOM-32 & SX1276/RF96 noname modules by Alexey Mikulik (#10)
    https://easyeda.com/spgsm/meshtastic-lite
2021-12-14 Add 3...8 el yagi
    [Elements.xlsx]
2021-12-21 Add 2nd release
    [BOM_MYSH_2021-12-18.xlsx]
2022-01-05 Del V2
    [BOM_MYSH_2021-12-18.xlsx]
2022-05-29 New PCBs (#11)
    * New PCBs design
    * Readme & preview
    [Meshtastic-DIY.brd, Meshtastic-DIY.sch, Meshtastic-DIY_v2.2.brd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]
2022-05-30 [PCB] Fixed `v1.04-TTGO-T8` & description update (#12)
    [Meshtastic-DIY_v4_TTGO-T8-18.brd, Meshtastic-DIY_v4_TTGO-T8-18.sch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]
2022-06-05 EBYTE E22 adapter board PCB (#13)
    * Adapter board for EBYTE E22-XXXM22S E22-XXXM30S
    * cropped images
    * link to the adapter board
    [E22-XXXMXXS.brd, E22-XXXMXXS.sch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]
2022-08-23 PCB updates (#15)
    * fixes PCB version and description
    * Updated revision of the v1.01 PCB
    * Fixed drill layout for v.1.05
    * Updated EBYTE E22 adapter (removed excessive antenna line)
    * Updated PCB v1.03
    * Updated PCB v1.02
    * Removed untested PCB design
    * [PCB] Missing brd&sch for 1.01 & updated 1.02
    * v1.04 update
    * [PCB] Meshtastic-DIY_v1.06 - TTGO T-Energy T18 V3.0 HAT
    [Meshtastic-DIY.brd, Meshtastic-DIY.sch, Meshtastic-DIY_v1.02.brd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]

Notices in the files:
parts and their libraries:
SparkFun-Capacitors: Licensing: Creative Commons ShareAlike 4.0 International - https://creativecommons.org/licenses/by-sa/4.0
